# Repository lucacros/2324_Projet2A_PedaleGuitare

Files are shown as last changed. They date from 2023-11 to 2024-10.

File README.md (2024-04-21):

# Hi everyone 🖐️ & Welcome to our project: Multi-Effects Guitar Pedal 🎸🎛️

Hello music and technology fans! Welcome to the GitHub showcase for our multi-effects guitar pedal project. Here you'll find details, tools, and resources related to this exciting project. This is an academic project completed in 100 hours by the legendary trio: Luca CROSETTO, Jolan THOMASSET, and Camille LANFREDI

## 📖 Table of contents

- [📌 Présentation](#-présentation)
  - [📅 Management Section](#-management-section)
  - [🛠️ Hardware Section](#-hardware-section)
  - [💻 Software Section](#-software-section)
- [🚀 Contributions](#-contributions)
- [📜 Licence](#-licence)

## 📌 Présentation

Our multi-effects guitar pedal project aims to provide a versatile platform for guitarists, bringing together a variety of sound effects and audio processing tools in a single device. To achieve this, the guitar pedal will feature...

The project is divided into 3 parts: the first one is the project management, the second part is analog part, with the creation of the system's electronic board, and the third is the creation of the various digital audio effects. 
The second is the creation of the various digital audio effects.

## 📅 Management Section

In this section, you'll find everything to do with project management.

[Link to Management.md](Management.md)

## 🛠️ Hardware Section

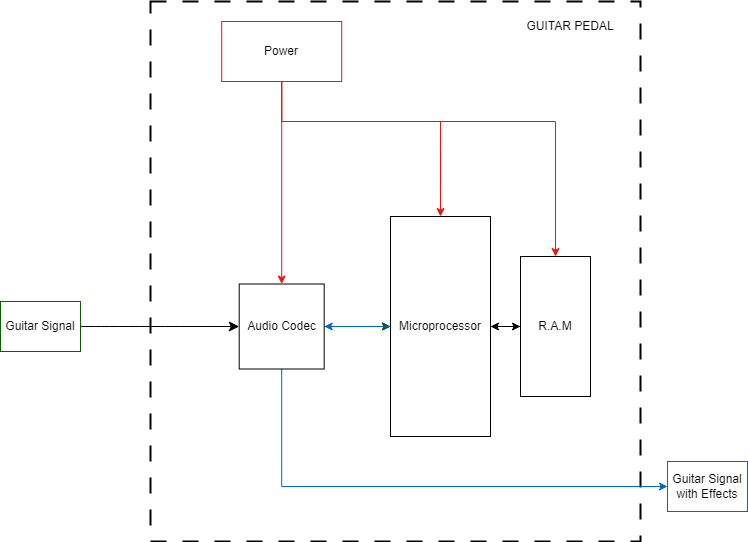
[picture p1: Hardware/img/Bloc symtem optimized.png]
 
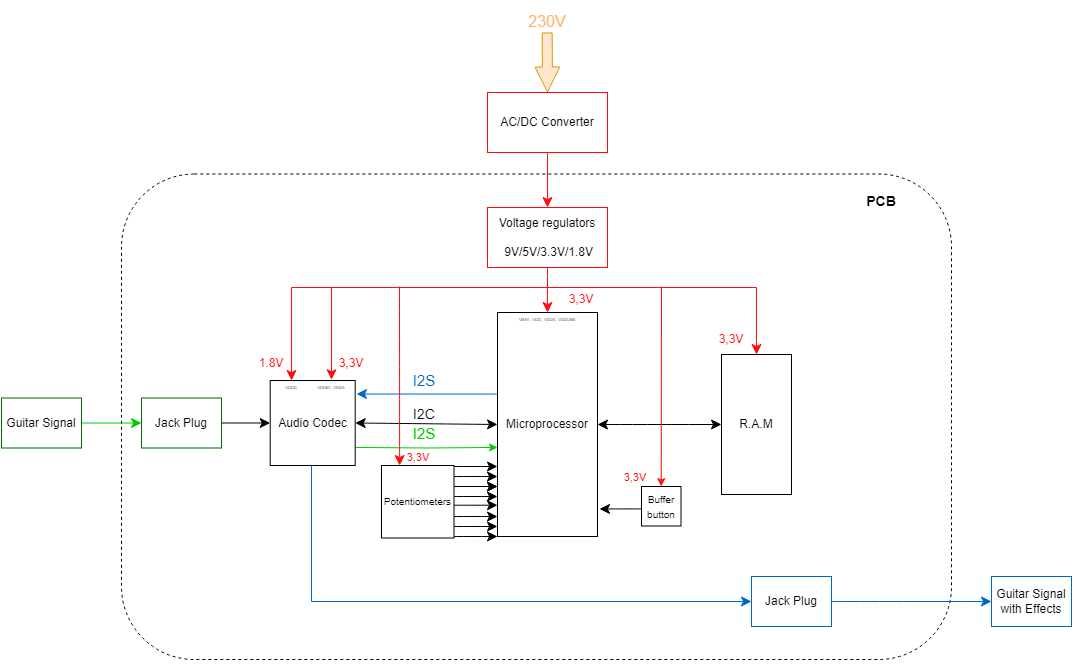
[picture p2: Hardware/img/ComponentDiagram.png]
 

### Power supply
To obtain these voltage levels, we use several voltage regulators. The first regulator is a switching regulator to go from 12V to 5V and then we use 2 linear regulators to obtain 3.3V and 1.8V. We first use a switching regulator to go from 12V to 5V, because switching regulators are more efficient than linear regulators when the voltage difference between input and output is high. We use linear regulators because they give a very clean output, with a minimum of noise.

We need to supply 2 different voltages: the first +3.3V to supply VDDA (for analogue part) and VDDIO (for Inputs/Outputs) and the second +1.8V to supply VDDD (for digital part).

| Components | Voltages |  Description |
|--- |:-: |:- |
| VDDIO | +3.3V | Power supply controls the digital I/O levels as well as the output level of LINE outputs. | 
| VDDD | +1.8V  | power supply controls the digital I/O levels as well as the output level of LINE outputs |
|  VDDA  | +3.3VA | Power supply is used for the internal analog circuitry including ADC, DAC, LINE inputs, MIC inputs, headphone outputs and reference voltages.|

#### Jack connecting
We use Jack switched for the input and the output of the guitar. The switched Jack allow us to have the choice between a mono-input or a stereo input and a mono-output and a stereo-output. 
When we connect a jack to this connector, the pins SN and TN are disconnected from the pins S and T. It can allow to have 2 connectors to have stereo but still use the 2 input of the codec to have a signal as powerful as a stereo input.
#### Buffer-Button
We use a buffer button to store a part of the sound of the guitar to apply several effects to it. It's one of the several options that offer the granular effect.
When the button is pressed, a signal is sent to the microprocessor. When it receives the signal, the microprocessor stores in the RAM the song it has received for a short time and continuously plays the part stored in the RAM.
#### Potentiometers
We use several potentiometers for all the settings of our effects, the gain, the shape, the reverb ect... All potentiometers are fitted with capacitors to eliminate unwanted noise and high frequencies.

They are 2 versions of the pcb :
| V | Recto | Verso  | Size |
|---|---|---|-----|
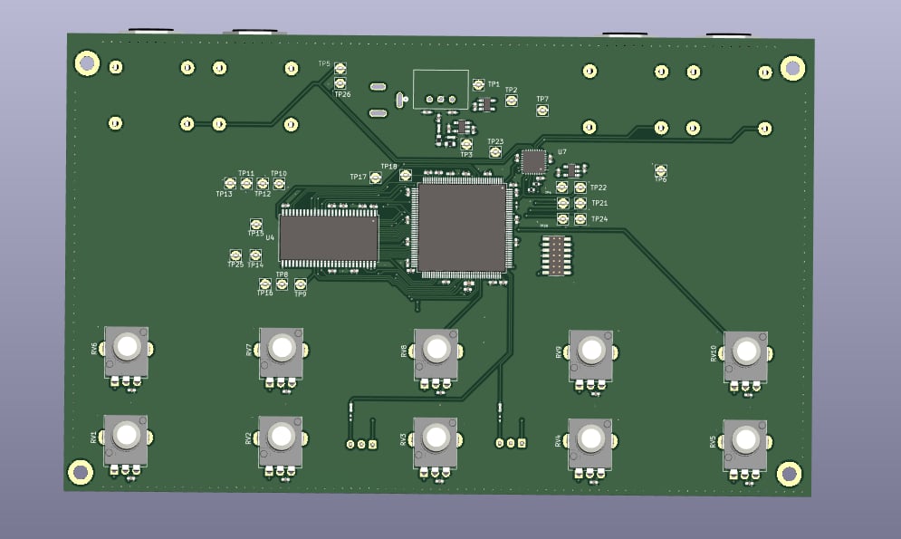
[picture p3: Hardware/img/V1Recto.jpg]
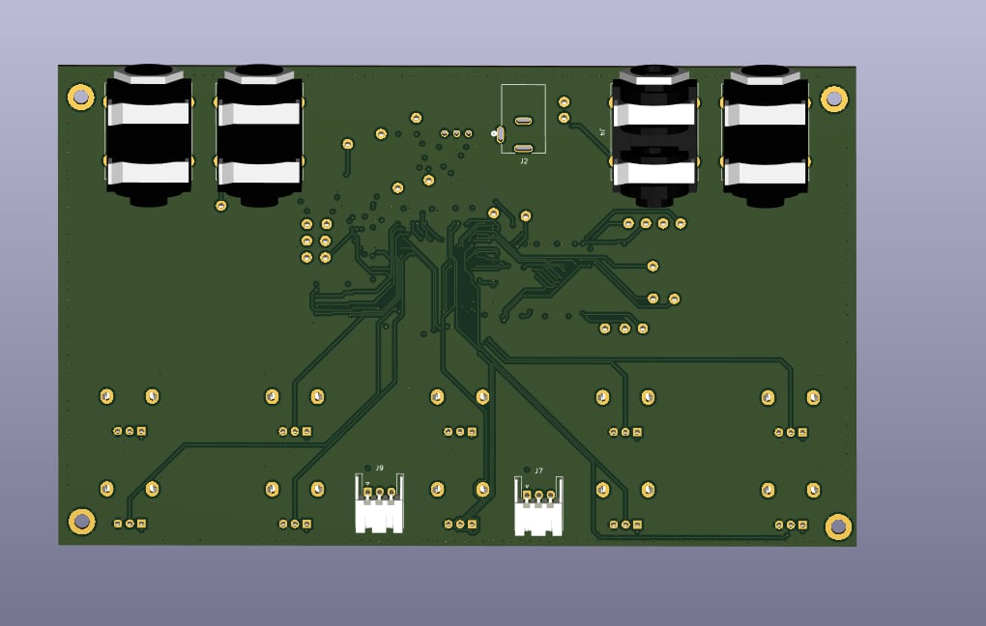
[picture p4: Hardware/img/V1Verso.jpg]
| V1.0|  | | 17 x 10.32 cm |
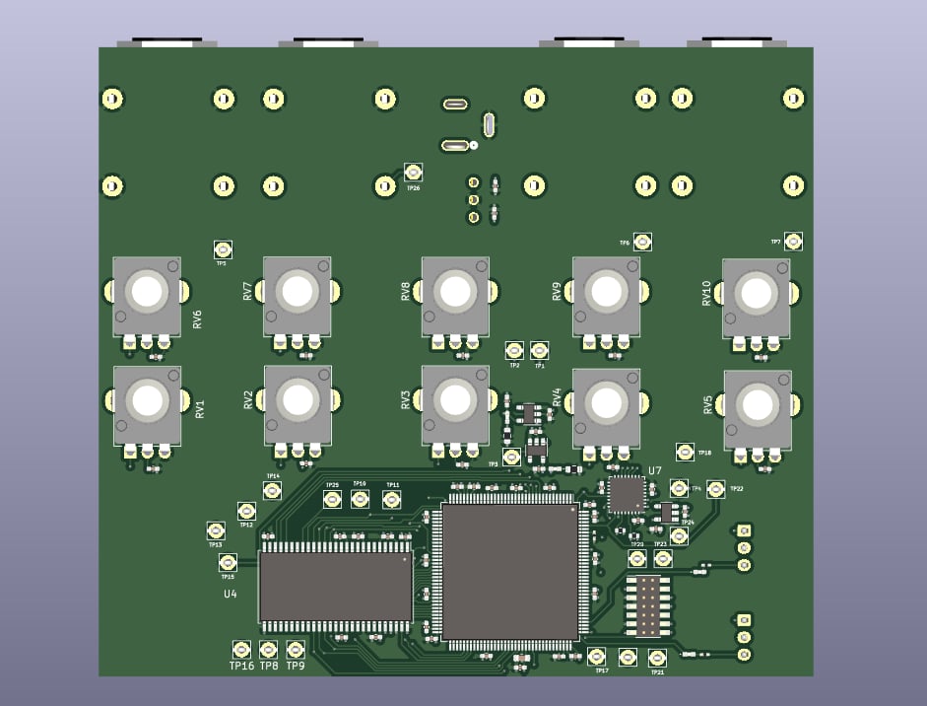
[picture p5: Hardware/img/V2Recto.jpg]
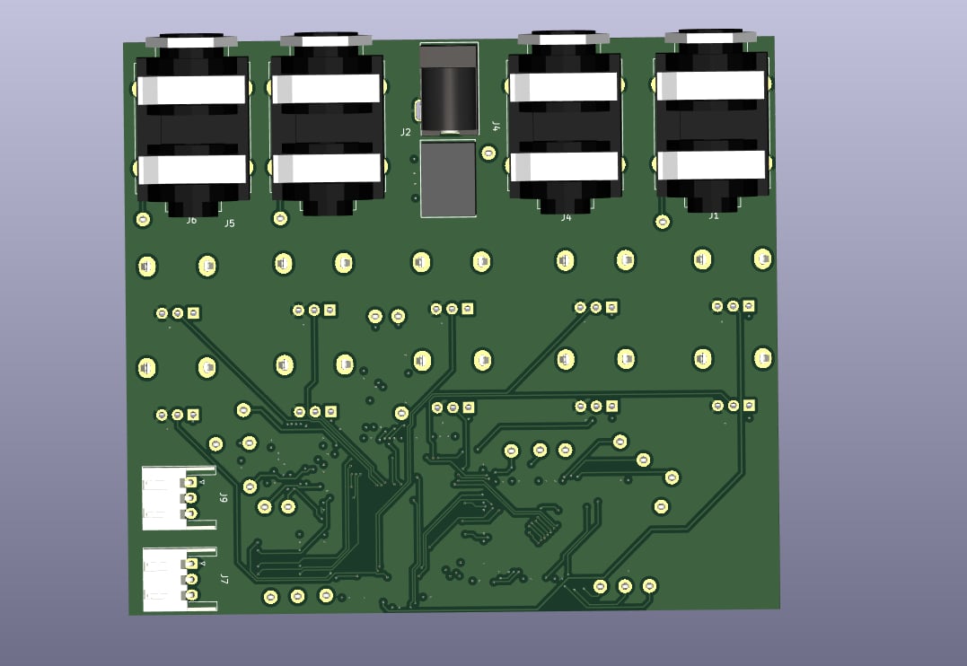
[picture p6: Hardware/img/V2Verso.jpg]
| V2.0|  | | 10.4 x 9.15 cm |
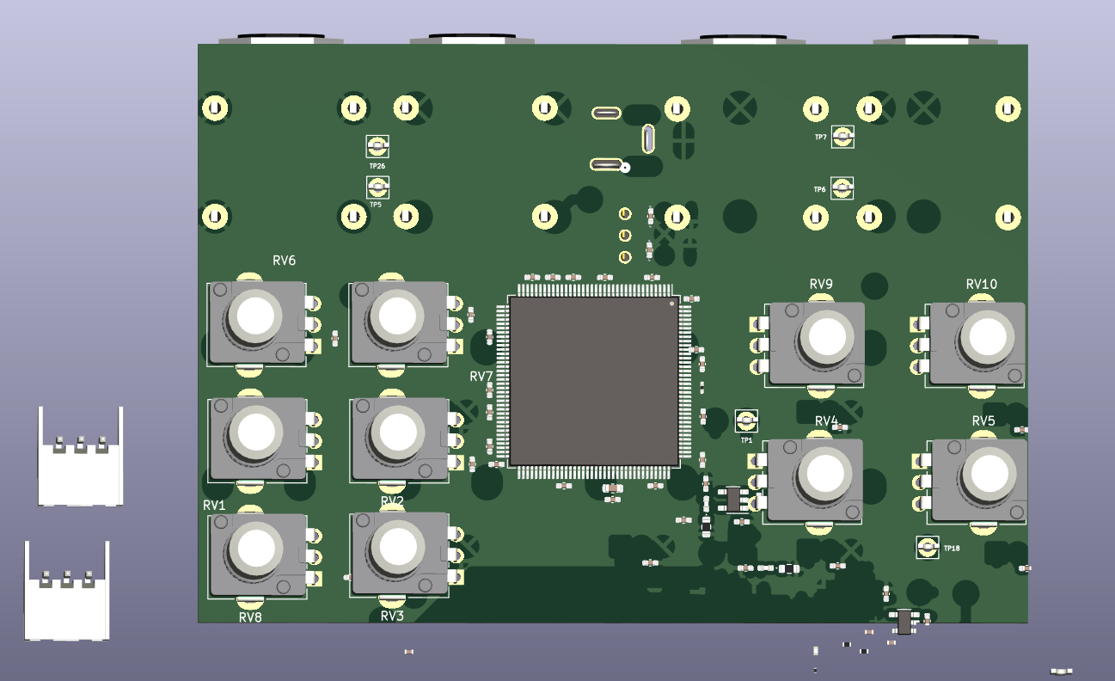
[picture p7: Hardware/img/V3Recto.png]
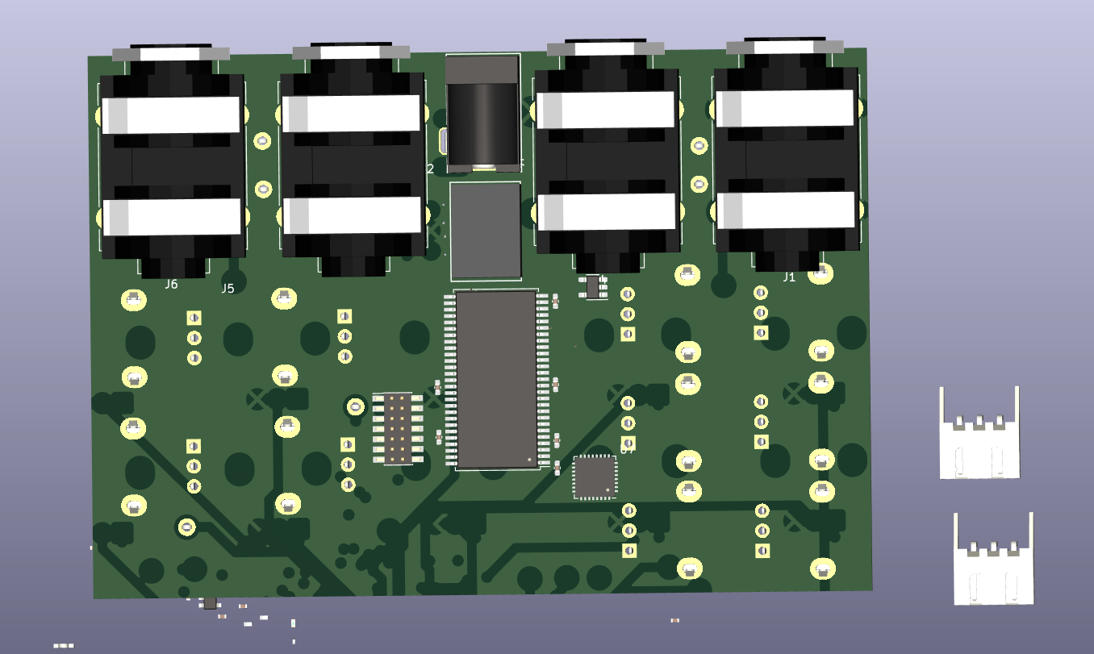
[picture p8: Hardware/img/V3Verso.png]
| V3.0| **WIP**  | **WIP**| 9.71 x 6.76 cm |

As you can see, the first version wasn't optimised. They is a lot of space between components and the design is not very good. That's why we did a new version witch to x2 smaller.

## 💻 Software Section

In this second part you will find everything that concerns the software part of the project. You'll find all the detailed audio effects programs and how they work.

[Link to Software Section](https://github.com/lucacros/2324_Projet2A_PedaleGuitare/tree/Software-Section)

## 🚀 Contributions

We would like to thank each person who helped us and provided support and information, such as:
- M. Nicolas PAPAZOGLOU
- M. Laurent FIACK
- M. Frédéric GERALDO

## 📜 Licence

The project is under the [SI TU VOLES T'ES MORT] license. Refer to the `LICENSE` file for more details.

---
Feel free to star this project (⭐) if you find it interesting!

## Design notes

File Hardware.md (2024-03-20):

# Here you are in the Hardware Section
You will find all specifications and things to understand it.
Enjoy your reading ! (Camille L)

## 📖 Table of contents
1. [List of components](#list-of-components)
2. [Hardware Specifications](#hardware-specifications)
3. [Installation](#installation)

## List of components
- [Link to List of Components](https://github.com/lucacros/2324_Projet2A_PedaleGuitare/blob/Hardware-Section/List%20of%20Components.md)

For more details on each component, refer to [Hardware Specifications](#hardware-specifications).

# Hardware Specifications
## Block Diagram

<p align="center">
  Block Diagram Optimized
</p>

Once the block diagram has been constructed, we can adapt it to the components used:

<p align="center">
  
</p>

## Power supply
The power dissipated in the electronic component used in switching mode is lower than when used in linear mode. They are 2 types of power for this pedal. Power of digital components and for analog components. That's why we have, the objective is to obtain the cleanest power source for our analog components such as : DAC and ADC. 
    
| Components | Voltages |  
|--- |:-: |
| MicroProc | +3.3V | 
|  Codec | VDDIO :+3.3V VDDD : +1.8V VDDA : +3.3V  | 
| RAM | +3.3V | 

To obtain these voltage levels, we use several voltage regulators. The first regulator is a switching regulator to go from 12V to 5V and then we use 2 linear regulators to obtain 3.3V and 1.8V. We first use a switching regulator to go from 12V to 5V, because switching regulators are more efficient than linear regulators when the voltage difference between input and output is high. We use linear regulators because they give a very clean output, with a minimum of noise.

### Switching power supply

The 17950x78 integrates both the input and output capacitors. Therefore, additional external input and output capacitors are normally not required.
The additional 100µF capacitor C1 is mounted as termination of the supply line and provides a slight damping of possible oscillations of the series resonance circuit represented by the inductance of the supply line and the input capacitance. This capacitor also prevents voltage overshoot during start up. the capacitor C3 allows fine tuning of load transcient voltage response.

### Linear power supplies
We use 3 linear regulators to lower the voltage to very clean outputs.

- 5V to 3.3V, for every components.


- 3.3V to 1.8V, for the audio codec.
<p align="center"><img src="img/Linear_supply_1V8.png></p>

## Audio Codec 

The SGTL5000 is a digital-to-analog (DAC) and analog-to-digital (ADC) audio codec. Its basic operation involvesconverting analog signals to digital for audio input and converting digital audio signals to analog for audio output. The essential pins include those for I2S communication, power supply, mode selection, audio input and output connections, as well as control pins to configure the codec based on application requirements.
Using the microcontroller, we will control the I2C codec and transmit the signals in I2S.

<p align="center">
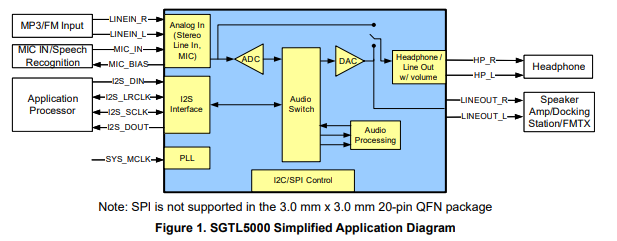
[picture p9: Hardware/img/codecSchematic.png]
  
</p>

### Power Section
To begin, we need to supply 2 different voltages: the first +3.3V to supply VDDA (for analogue part) and VDDIO (for Inputs/Outputs) and the second +1.8V to supply VDDD (for digital part).

| Components | Voltages |  Description |
|--- |:-: |:- |
| VDDIO | +3.3V | Power supply controls the digital I/O levels as well as the output level of LINE outputs. | 
| VDDD | +1.8V  | power supply controls the digital I/O levels as well as the output level of LINE outputs |
|  VDDA  | +3.3VA | Power supply is used for the internal analog circuitry including ADC, DAC, LINE inputs, MIC inputs, headphone outputs and reference voltages.|

### Configuration
The codec is clocked at the same frequency as the microprocessor. It communicates via I2C  and transmits its audio data in I2S.

| Label names | Codec Pins name | Description |
|---|---|---|
| **Guitar signal** | | 
| Ve_guitare_L | LINEIN_L | Left LINEIN | 
| Vs_guitare_L | LINEOUT_L | Left LINEOUT |
| Ve_guitare_R | LINEIN_R | Right LINEIN | 
| Vs_guitare_R | LINEOUT_R |Right LINEOUT |
| **Clock** | | 
| SYS_MCLK | SYS_MCLK | System master clock |
| **I2C** | | 
| SDA_I2S | CTRL_DATA | Mode: Serial Data |
| SCL_I2C | CTRL_CLK | Mode: Serial Clock |
| **I2S** | | 
| WS_I2S | I2S_LRCLK | Frame clock |
| CK_I2S | I2S_SCLK | Bit clock |
| DOUT_I2S | I2S_DOUT | Data output |
| SD_I2S | I2s_DIN | Data input |

## RAM 
For the granular effect, we need to store part of the sound that the guitar sends and read this sound. The RAM on the CPU was not enough to store all the information we needed, so we decided to use an external RAM.
To use the RAM we need to connect the Address pin to the CPU to send the information of which memory address we want to access in the RAM. The Data pin is used to send the information stored in the RAM to the CPU.
We have connected the RAM clock to the CPU clock so that the RAM and CPU work at the same speed.
## MicroProcessor 
The microprocessor is a crucial component in the guitar pedal system, responsible for controlling various functions, processing audio signals, and managing communication with other components. In this section, we'll delve into the specifications and details related to the microprocessor.
### MicroProcessor Pins
The microprocessor interacts with other components through various pins. Here are some essential pins and their functions:
### Power Supply Pins
| Pins | Voltages |  
|--- |:-: |
| VDDIO | +3.3V | 
| VDDD | +1.8V  | 
|  VDDA  | +3.3V | 
### Communication with RAM
The STM32F446ZC communicates with the RAM to handle memory operations. RAM is crucial for storing and accessing data during signal processing.
### Communication with Audio Codec
The microprocessor communicates with the audio codec (SGTL5000) using I2C for control and I2S for audio data transmission. The codec is responsible for converting analog signals to digital and vice versa.
- [Link to the Routing table](https://github.com/lucacros/2324_Projet2A_PedaleGuitare/blob/Hardware-Section/Routing_Table.md)
## Connectors
### Jack connecting
We use Jack switched for the input and the output of the guitar. The switched Jack allow us to have the choice between a mono-input or a stereo input and a mono-output and a stereo-output. 
When we connect a jack to this connector, the pins SN and TN are disconnected from the pins S and T. It can allow to have 2 connectors to have stereo but still use the 2 input of the codec to have a signal as powerful as a stereo input.
## Buffer-Button
We use a buffer button to store a part of the sound of the guitar to apply several effects to it. It's one of the several options that offer the granular effect.
When the button is pressed, a signal is sent to the microprocessor. When it receives the signal, the microprocessor stores in the RAM the song it has received for a short time and continuously plays the part stored in the RAM.
## Potentiometers
We use several potentiometer for all the settings of our effects, the gain, the shape, the reverb ect... All potentiometers are fitted with capacitors to eliminate unwanted noise and high frequencies.
## 💻 Installation
I recommend downloading the latest version of **KiCad** to reproduce the electronic board. For simulating amplifiers, consider using **Cadence Pspice** or **Microcap**. Use the **STCUBEIDE** software for programming the codec and microprocessor.
- **Pspice**: [Download Pspice](https://www.cadence.com/en_US/home/tools/pcb-design-and-analysis/analog-mixed-signal-simulation/pspice.html)
- **KiCad**: [Download KiCad](https://www.kicad.org/)
- **STCUBEIDE**: [Download STCUBEIDE](https://www.st.com/en/development-tools/stm32cubeide.html)

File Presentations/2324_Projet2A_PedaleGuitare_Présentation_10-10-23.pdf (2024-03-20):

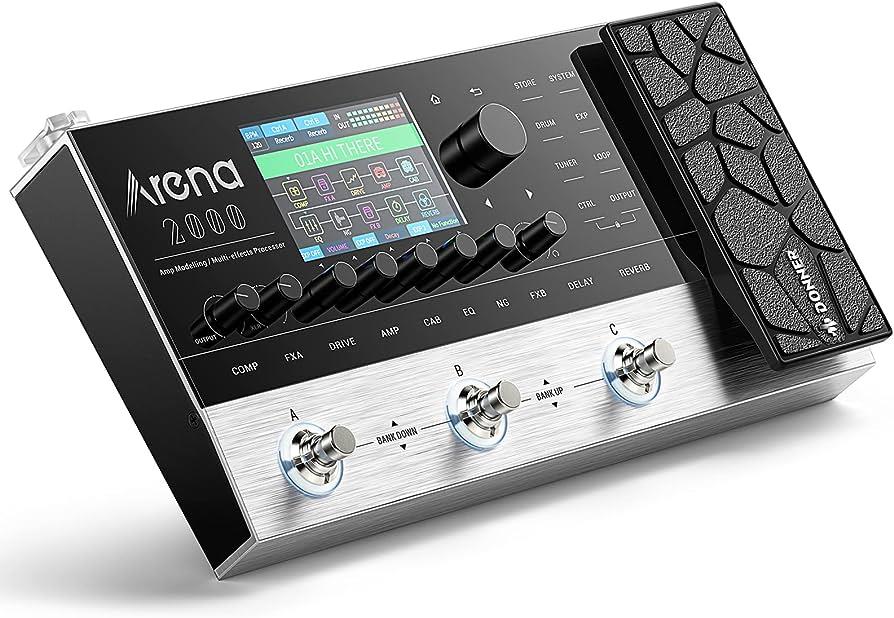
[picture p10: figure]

# Pédale Multi-Effets Numérique

Camille LANFREDI
Luca CROSETTO
Jolan THOMASSET

1

## Sommaire

- Introduction (3)
- Présentation du projet (4-5)
- État de l'art (6)
- Cahier des charges (7)
- Spécifications techniques (8-12)
20/03/2024 | Camille Luca Jolan | 2

## Introduction

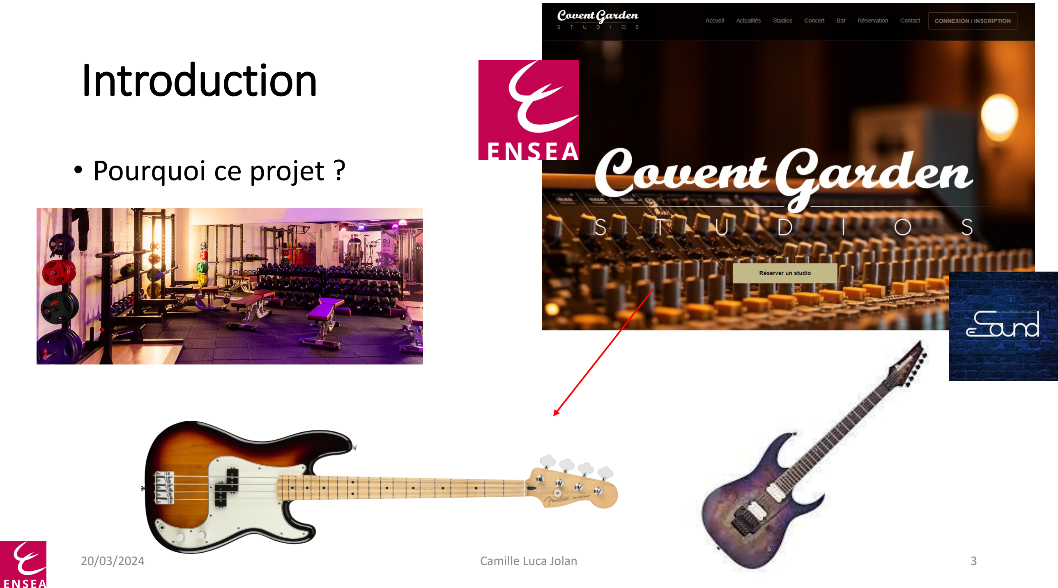
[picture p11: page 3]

- Pourquoi ce projet ?

## Présentation du projet 1/2

- Clients : Les adeptes de la musique (M. Fiack, M. Papazoglou) & les guitaristes
- Contexte – Contraintes
3 étudiants (2 élec-info / 1 signal-élec)
Une pédale à réaliser avec divers effets numériques ( Octaver, Saturation, Granulaire...) Sur une période de ~ 100h encadrées dans l'établissement + ∞ h à la maison
Choix des composants, création de notre propre PCB, choix des effets et implémentations.

## Présentation du projet 2/2

- Enjeux :
Tout à gagner (compétences), MAIS on s'ouvre à perdre la confiance d'un prof qui a cru en nous.
- Objectifs :
Partie Electronique : choix des composants / PCB / Assemblage
Partie informatique : Implémenter des transformations de signal sonore
- Coûts :
Budget alloué par l'établissement, ~60-100€ par personne

## Etat de l'art

- Première pédale d'effet inventé en 1962 (La Maestro Fuzz Tone).
- A partir des années 80, apparitions des pédales numériques.
- Année 90, création des pédales multi-effets.
- Année 2000, création des plugins.

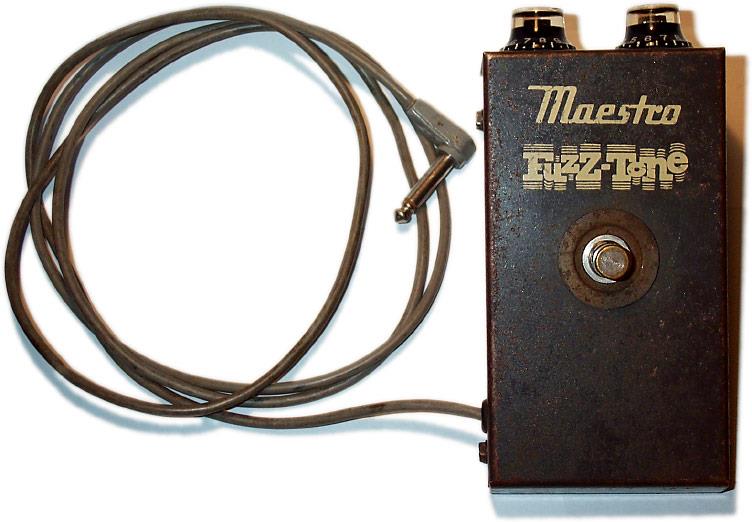
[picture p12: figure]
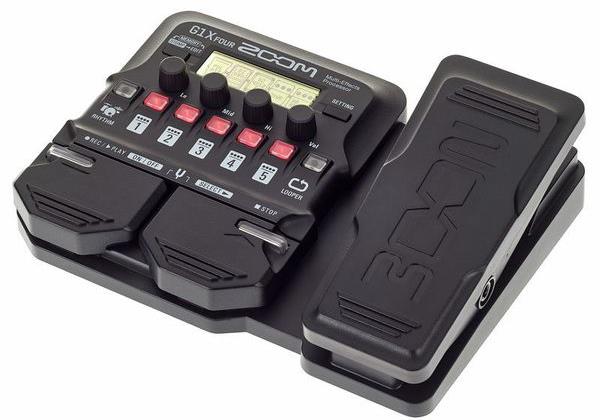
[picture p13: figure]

## Cahier des charges

- Fil Conducteur
Fabrication d'une pédale multi-effet.
- Spécifications techniques :
Représentation du système
Utilisation d'un codec audio.
Utilisation d'un microprocesseur lié à une RAM externe. Interprétation physique d'effet audio
Implémentation d'un effet audio numériquement Réussir à implémenter un effet "Granulaire"

Spécifications techniques - Représentation du système

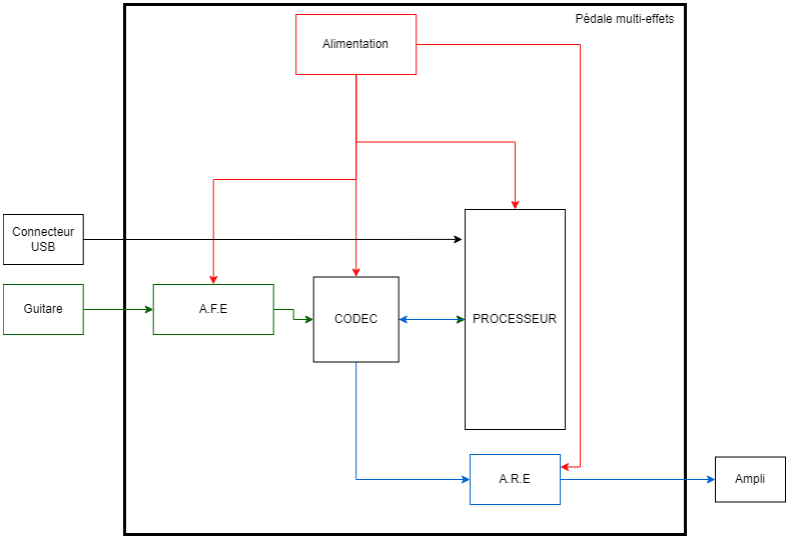
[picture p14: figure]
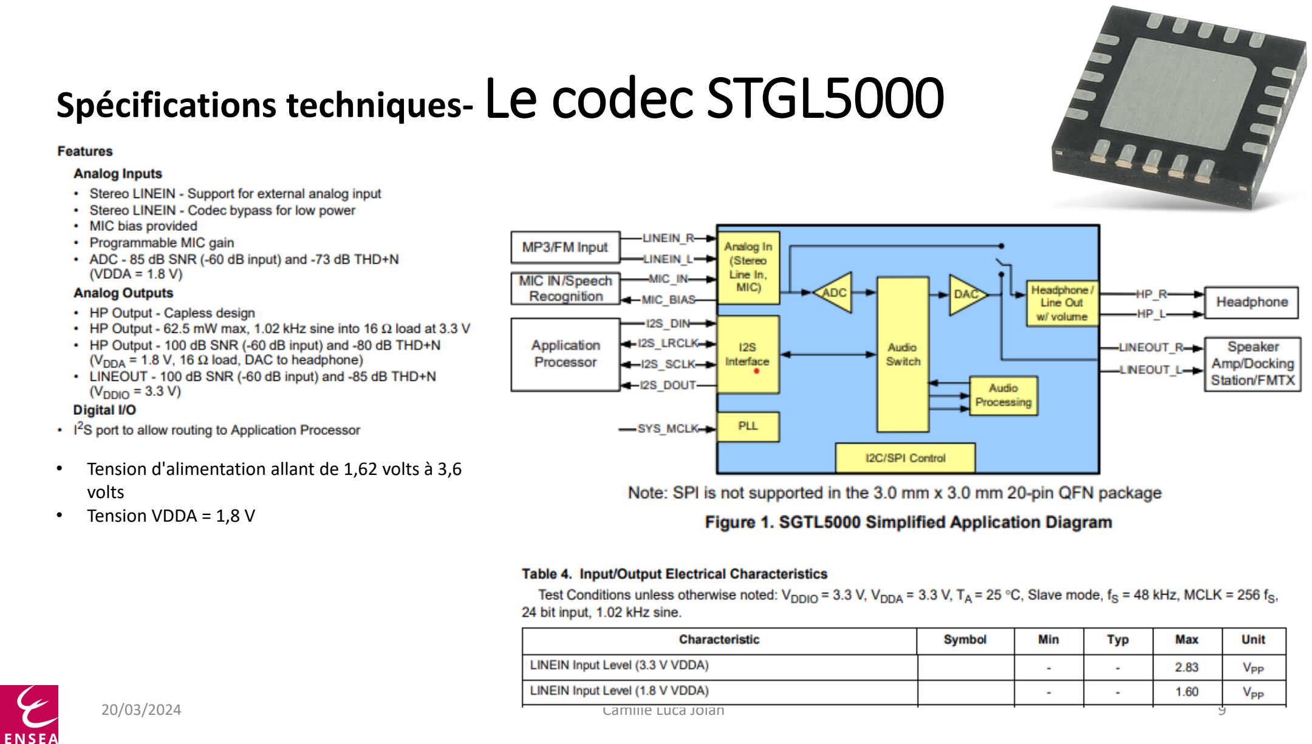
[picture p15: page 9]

Spécifications techniques- Le codec STGL5000

- Tension d'alimentation allant de 1,62 volts à 3,6 volts
- Tension VDDA = 1,8 V

Tension d'entrée max LINEIN_R et _L
Vmax = VDDA * 10^(Niveau d'entrée maximal en dB / 20)
Vmax = 1,8 V * 10^(-60 dB / 20) = 0,056 V

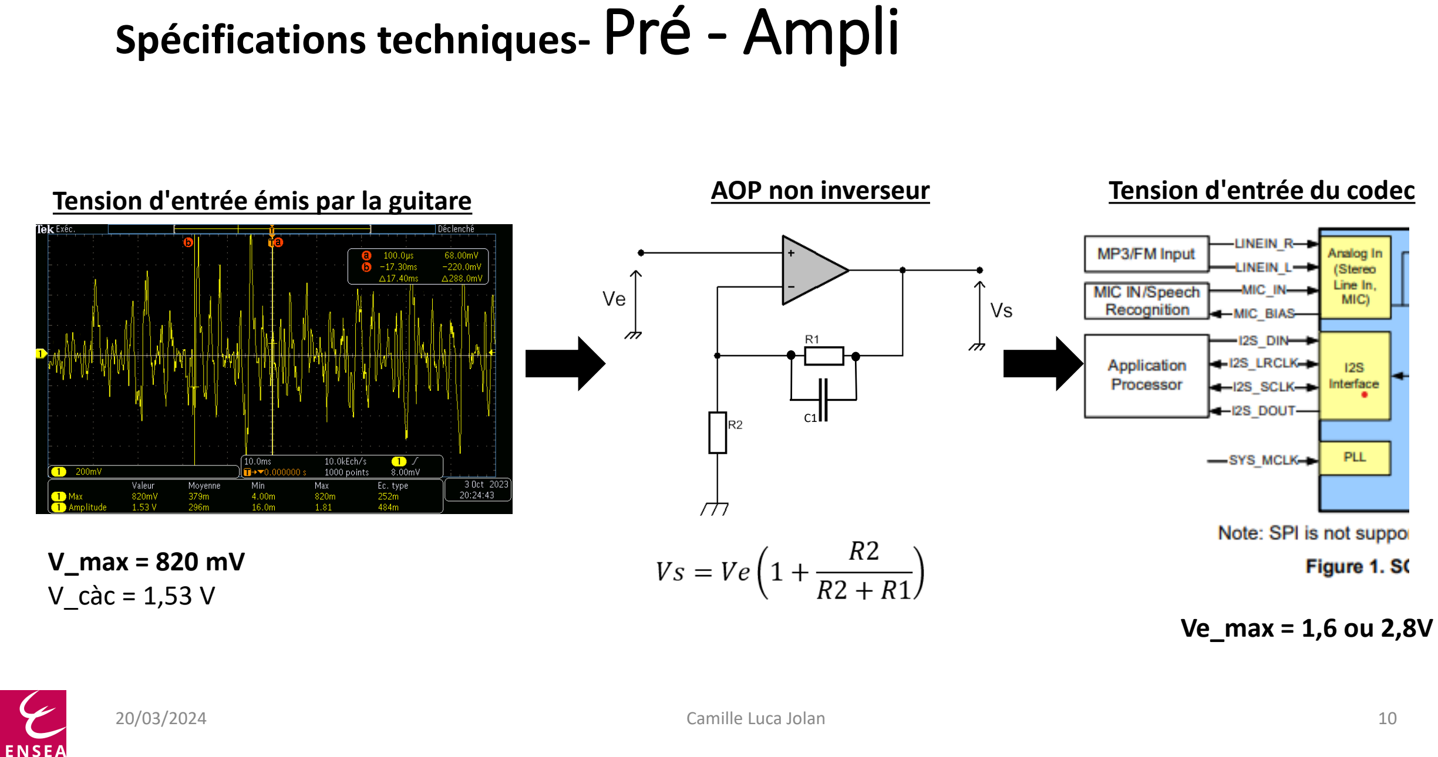
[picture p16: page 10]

Spécifications techniques- Pré - Ampli

Tension d'entrée émis par la guitare

V_max = 820 mV
V_càc = 1,53 V
AOP non inverseur | Tension d'entrée du codec

Ve_max = 1,6 ou 2,8V

C1

Spécifications techniques - LE Microprocesseur

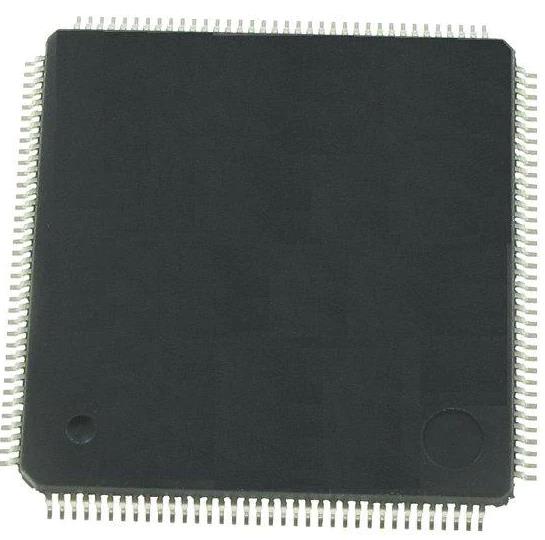
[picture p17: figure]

STM32f446ZCT6

Alimentation : Vdd et Vss = 3,3V

Mémoire :
- 512 Ko à 180 MHz
- 128 Ko RAM

Horloge : 4 à 26 MHz

114 entrées/sorties :

Interfaces de communication : SPI, I2C, UART, I2S

Inter-integrated sound (I2S) :
- Disponibles sur SP1, SP2 et SP3
- Fréquence d'échantillonnage : 8 kHz à 192 kHz
- Résolution de 16/32 bits

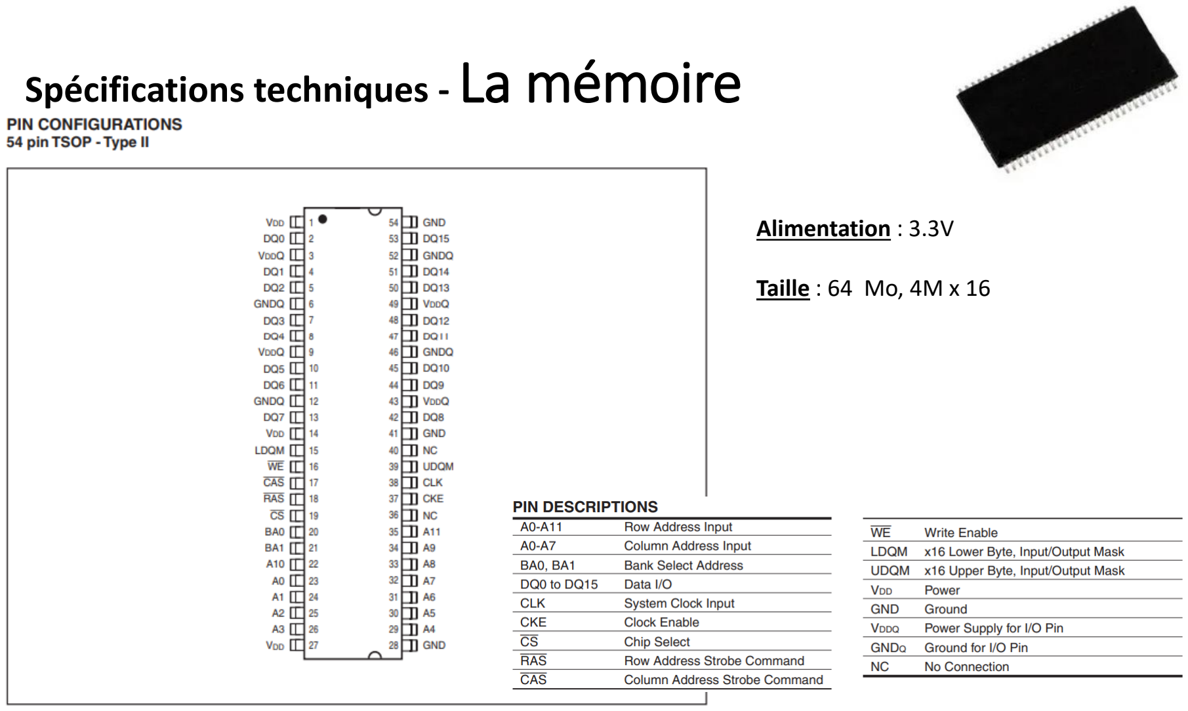
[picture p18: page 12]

Spécifications techniques - La mémoire

Alimentation : 3.3V

Taille : 64 Mo, 4M x 16

Spécifications techniques

## Implémentation

- Quel langage ? C, C++, Python
- Codage en amont : Librairie Portaudio (C++) permet d'obtenir une Input/Output son temps réel.
- Documentation sur la Physique de la modulation de notre signal sonore et l'effet qui correspond à cette modulation
- Code sur VCS & Suivi Github

Spécifications techniques

## L'Effet Granulaire

- Etude de l'effet à l'aide de Logiciel (durée d'un grain = typiquement de 1 à 100 ms).

La synthèse granulaire est une technique de traitement du son qui divise un signal sonore en petits grains (fragments) Ensuite les grains peuvent être manipulés de différentes manières pour créer un effet souhaité.

- Pitch : Contrôle la hauteur ou la fréquence du son granulaire généré
- Density : Contrôle la fréquence à laquelle de nouveaux grains sont générés.
- Shape : Permet d'influencer la façon dont les grains sont lus (passage enveloppe linéaire à exponentielle)
- Feedback : Le potard feedback détermine la quantité de signal granulaire qui est renvoyée. Plus on augmente le feedback, plus une partie du signal granulaire peut être renvoyée dans le processus, créant une boucle de rétroaction.
- Reverb : en augmentant la reverb, on crée une ambiance spatiale plus grande autour du son granulaire, donnant l'impression que le son se propage dans un espace plus grand

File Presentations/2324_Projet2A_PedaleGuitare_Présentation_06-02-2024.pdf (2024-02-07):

# Pédale Multi-effets (PME)

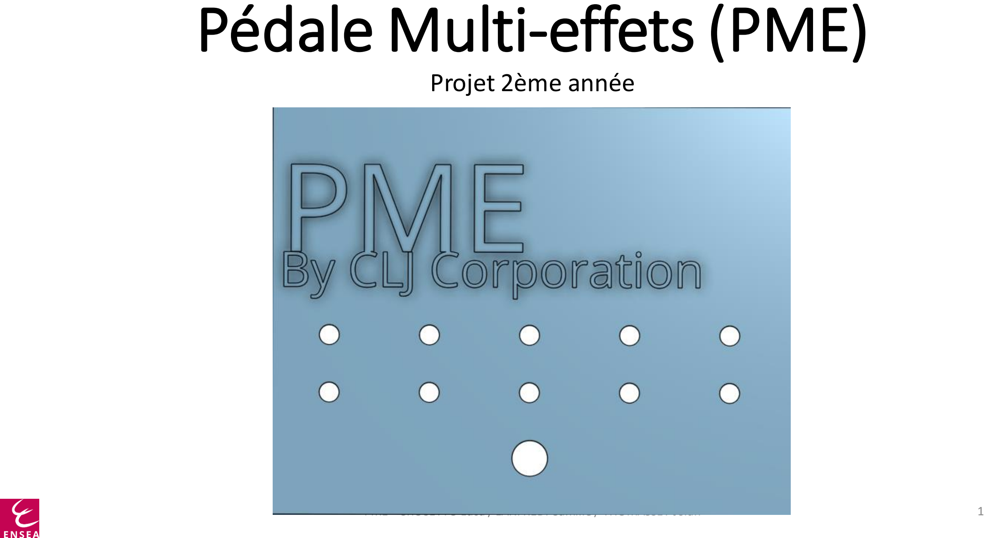
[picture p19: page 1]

Projet 2ème année

PME - CROSETTO Luca / LANFREDI Camille / THOMASSET Jolan | 1

## Objectifs atteints (12 Séances)

- Schéma PCB
- Composants
- Tests sur Guitare
- Prise en main du langage informatique FAUST
- Utilisation du CODEC avec restitution du signal entrée / sortie sur une carte son (STM32, CubeIDE).
- Création d'un effet simple de distorsion.

Cahier des charges
Créer une Pédale de Guitare :
- Carte électronique
- Boitier
Coder des Effets Numérique :
- IN/OUT Codec
- Effet simple
- Effet complexe

## Objectifs restants (10 séances)

- Création d'un boitier pour la pédale
- Finalisation du PCB.
- Prendre en compte les potentiomètres lors de la réalisation des effets.
- Effet numérique complexe
- Management (impact environnemental, etc...)

Cahier des charges
Créer une Pédale de Guitare :
- Carte électronique
- Boitier
Coder des Effets Numérique :
- IN/OUT Codec
- Effet simple
- Effet complexe

## Bilan SOFTWARE

- Réalisation d'un effet de Reverb en langage Faust

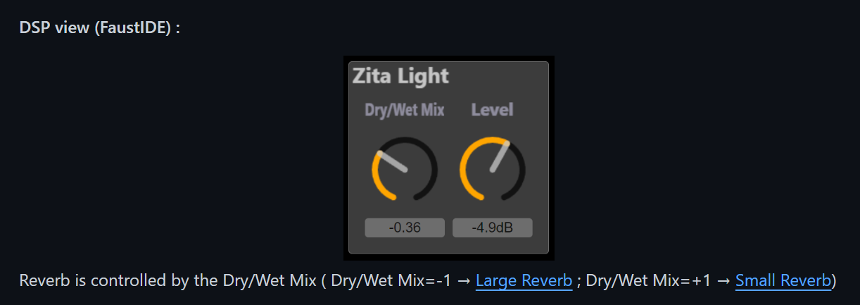
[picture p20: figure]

## Bilan SOFTWARE

- Restitution entrée/sortie par le biais d'un CODEC audio avec STM32

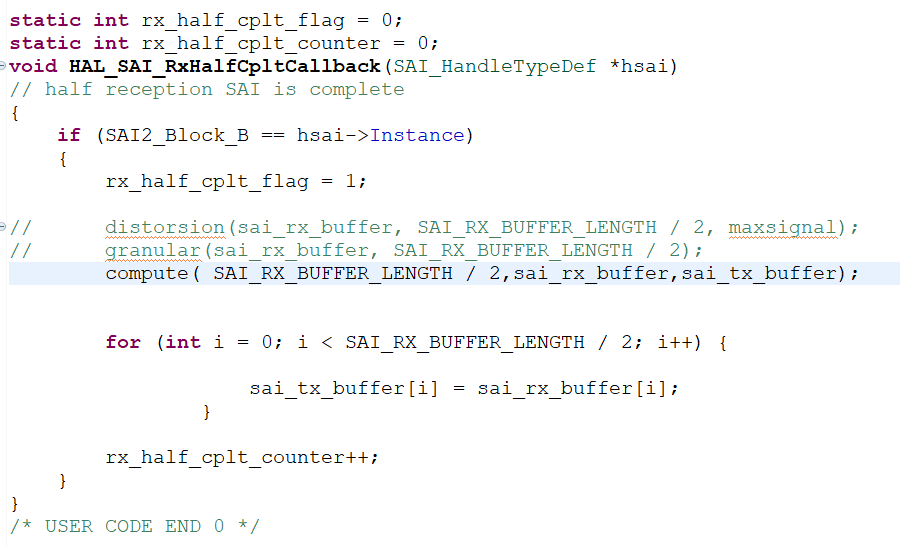
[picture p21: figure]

Int16_t ou Float
?

Question

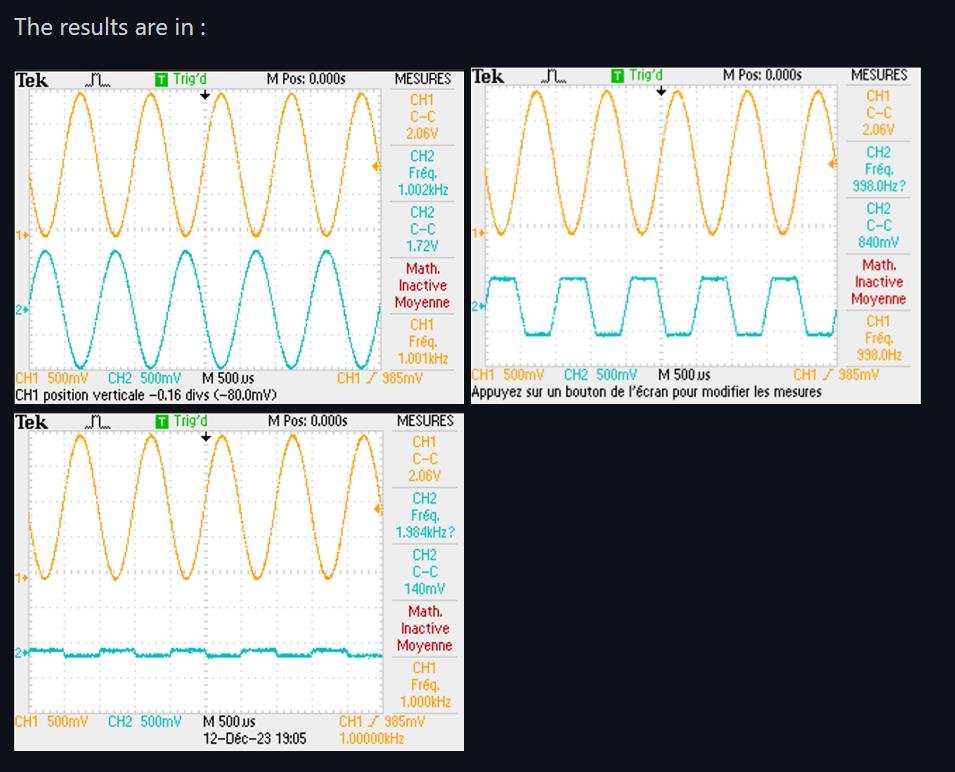
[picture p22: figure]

## Bilan SOFTWARE

- Effet Simple Distorsion
(distorsion.c, distorsion.h)

Ajustement de la valeur
Max à attribuer.

## Bilan SOFTWARE

- Effet Reverb by Faust (convert in Cpp)

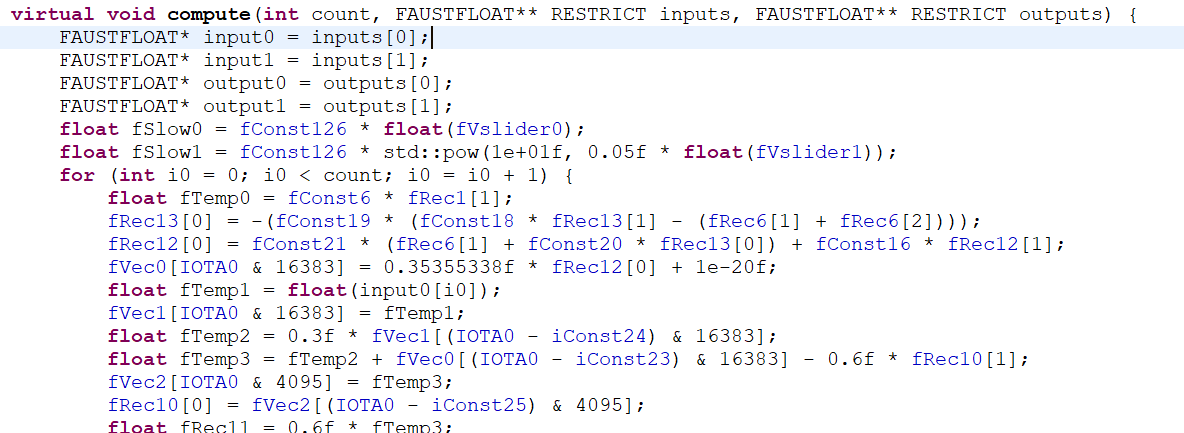
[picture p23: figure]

- Identification partie du code Intéressante
- Utilisation du code dans STM32

## Modélisation 3D du boitier de la pédale

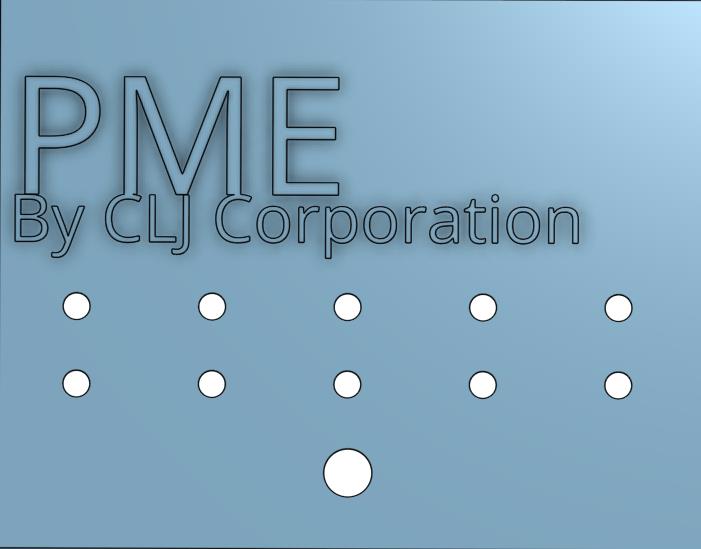
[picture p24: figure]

Vue de dessus

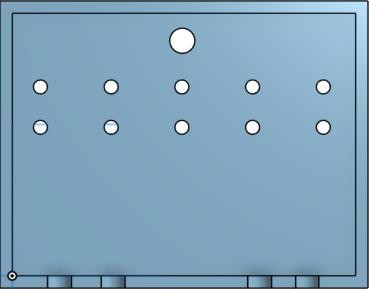
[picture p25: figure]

Vue de dessous

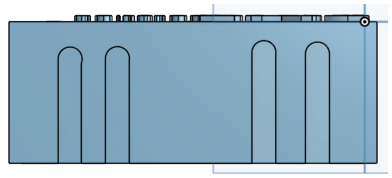
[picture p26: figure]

Vue de derrière

## Bilan HARDWARE

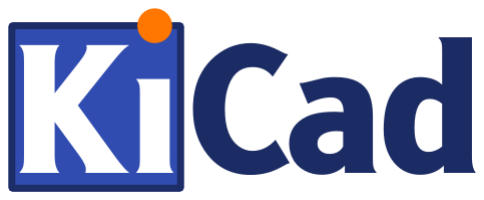
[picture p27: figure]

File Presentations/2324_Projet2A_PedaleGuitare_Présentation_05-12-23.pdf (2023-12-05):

# La Pédale de Guitare Numérique

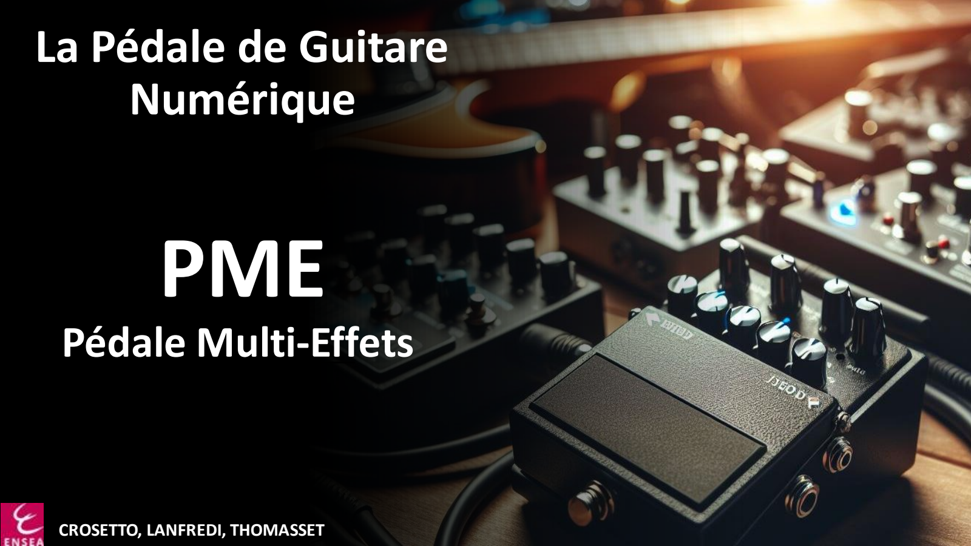
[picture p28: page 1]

# PME

## Pédale Multi-Effets

CROSETTO, LANFREDI, THOMASSET

# Sommaire

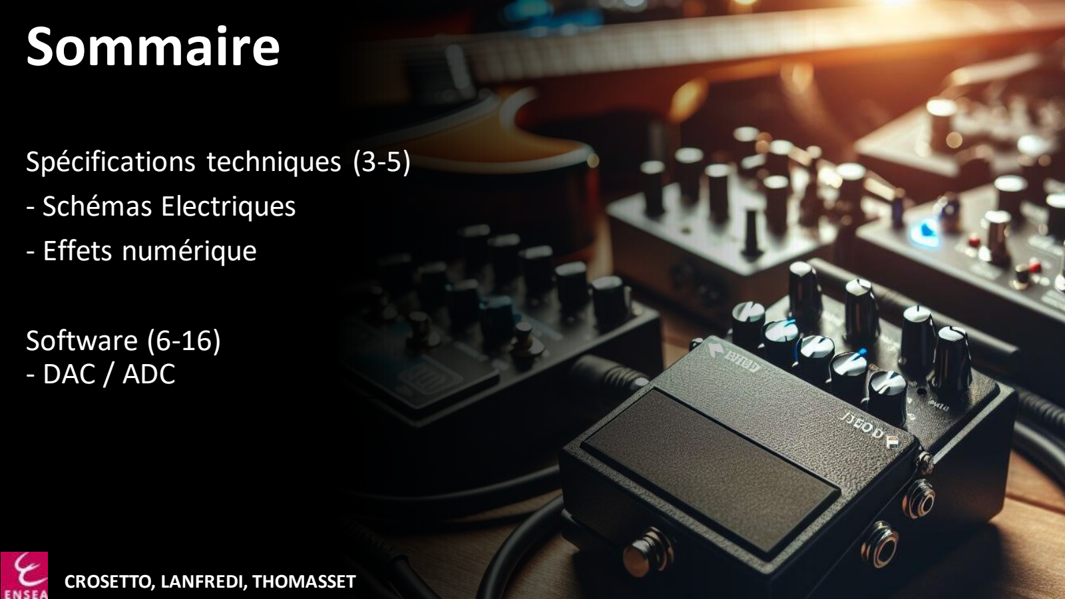
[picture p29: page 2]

Spécifications techniques (3-5)
- Schémas Electriques
- Effets numérique

Software (6-16)
- DAC / ADC

CROSETTO, LANFREDI, THOMASSET

## Spécifications techniques - Schéma Bloc de la pédale

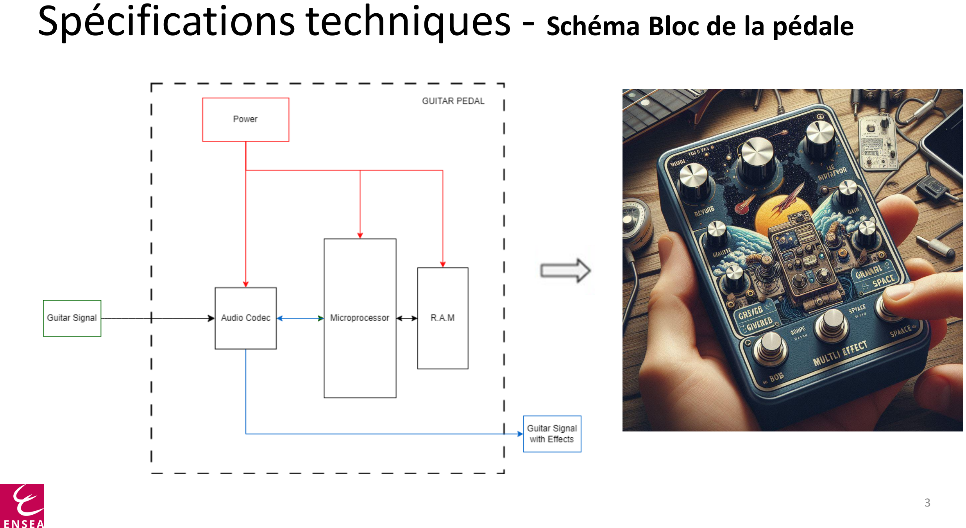
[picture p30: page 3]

## Spécifications techniques - Schéma Bloc de la pédale

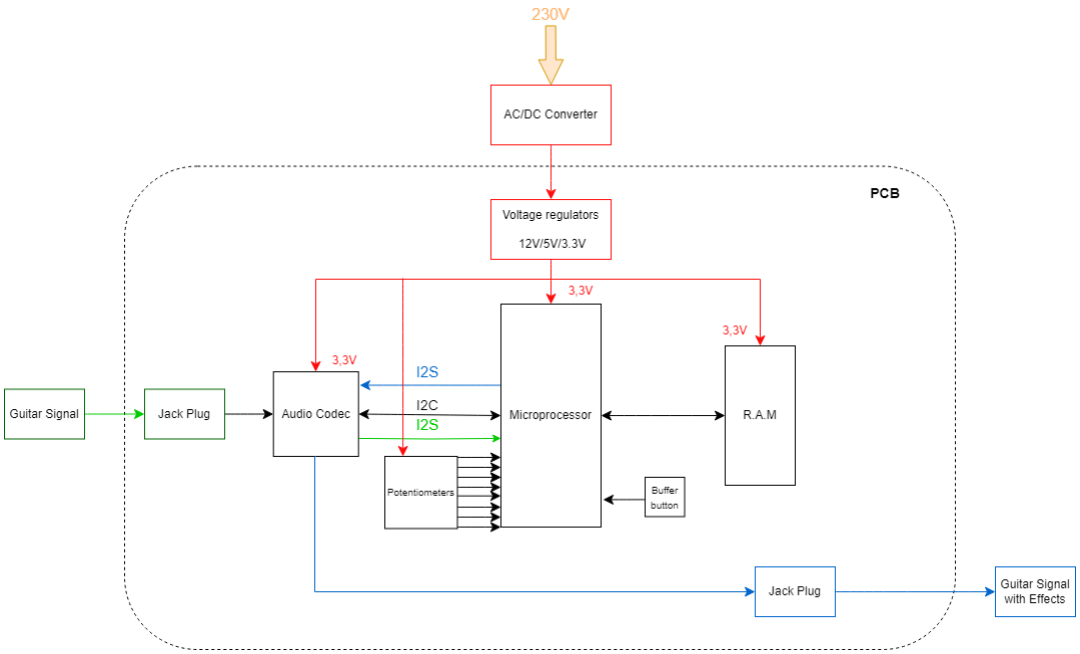
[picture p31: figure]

## Spécifications techniques - Schéma électrique

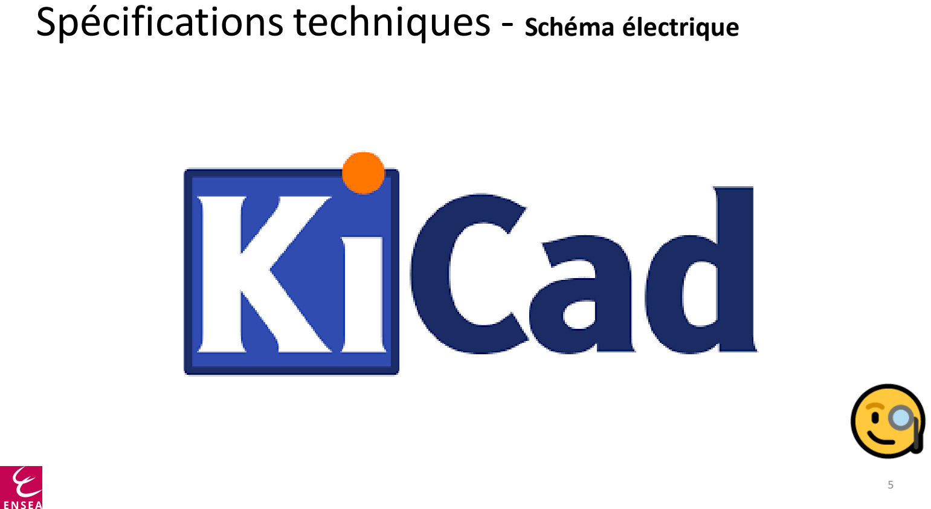
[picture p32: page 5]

## Software


- Coder un Effet en FAUST et le générer en C


- Capturer et afficher IN/OUT Audio sur

Reverb effect control

Software | Capturer et afficher IN/OUT Audio sur


# CODEC

Objectif Finale

EFFECT

With effect


With effect

Software | Capturer et afficher IN/OUT Audio sur

ADC; DAC; EFFECT

Analog Signal
With Effect

Objectif pour tester l'effet avant de se lancer dans l'utilisation du CODEC


Software | Capturer et afficher IN/OUT Audio sur
ADC | DAC

Dans un premier temps :

Software | Capturer et afficher IN/OUT Audio sur

Démarrage avec le DAC ( partie avec l'ADC déductible )

Ioc view

DAC codé sur 12 bits

Valeur comprise entre 0 et 4095

Étape 1 : afficher un signal qui monte jusqu'à 4095 et qui redescend à 0

DAC

Software | Capturer et afficher IN/OUT Audio sur

Étape 2 : Utilisation d'un DMA (Direct memory access)


Software | Capturer et afficher IN/OUT Audio sur

Étape 2 : Utilisation d'un DMA

Déclenchement par TIMER (et non plus pas Trigger)


Création du DMA
Stocker une période et la jouer en boucle (12bits)

Configuration du TIMER

TIM8 sur APB2

Clock configuration view

Fréquence Audio 48kHz

Le taux d’échantillonnage pour l’audio “professionnel”

(180.10⁶)/(48.10³) = 3750

ARR * PSC = 3750

ARR = 3750 –1 PSC = 1

DAC

Software | Capturer et afficher IN/OUT Audio sur

Configuration du TIMER


Relie TIM8 automatiquement
Création du Buffer

Dent de scie pour 48kHz, MAX 4096 MIN 0

On mesure bien une fréquence de 1kHz à l'oscilloscope

DAC

Software | Capturer et afficher IN/OUT Audio sur
ADC
ADC fonctionne entre 0 et 3,3 V | [-0,7 ; +3,3] | GBF sinus 1V/div.

Mise en Place d'interruptions; ADC; DAC; Buffer

Software | Capturer et afficher IN/OUT Audio sur
ADC

Software | Capturer et afficher IN/OUT Audio sur
ADC DAC


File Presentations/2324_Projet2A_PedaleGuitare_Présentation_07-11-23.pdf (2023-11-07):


# Pédale Multi-Effets Numérique

## Camille LANFREDI Luca CROSETTO Jolan THOMASSET

07/11/2023 | 1

# Sommaire

## - Spécifications techniques (8-12) - Schémas Electriques - Effets numérique

# Spécifications techniques - Schéma Bloc de la pédale


# Spécifications techniques – Préamplificateur


07/11/2023 | Camille Luca Jolan | 4

Tension d'entrée émis par la guitare

V_max = 820 mV
V_càc = 1,53 V
AOP non inverseur | Tension d'entrée du codec

Ve_max = 1,6 ou 2,8V

C1

# Spécifications techniques – Préamplificateur

## - Simulation


# Spécifications techniques – Préamplificateur et

# Amplificateur de sortie


# Spécifications techniques – Connexion Codec / µP


- Connexion I2C pourla communication
- Communication série (SPI ou I2S) pour l'audio
- Entrées/sorties audio
- Alimentation/Miseà la terre et autres connexions

Broches du codec SGTL5000 (selon la datasheet typique) : •SDA: Broche de données pour l'I2C
•SCL: Broche d'horloge pour l'I2C
•RESET: Broche de réinitialisation du codec
•MCLK: Horloge maître (peut être utilisée pour I2S) •LRCLK: Horloge de canal gauche/droite (utilisée pour I2S) •BCLK: Horloge de bits (utilisée pour I2S)
•DIN: Données d'entrée (utilisée pour I2S)
•DOUT: Données de sortie (utilisée pour I2S)
•MIC/GPIO: broche de micro ou de GPIO (entrée/sortie générale) •VDDIO: Alimentation pour les signaux d'entrée/sortie
•VDDA: Alimentation analogique
•VDDD: Alimentation numérique

# Spécifications techniques - Connexion µP/RAM


- Connexion I2C pourla communication
- Communication série (SPI ou I2S) pour l'audio
- Entrées/sorties audio
- Alimentation/Miseà la terre et autres connexions

Brochage de la mémoire :
•D0-D15 : Lignes de données bidirectionnelles. •A0-A11 : Lignes d'adresse pour la mémoire •BA0-BA1 : Lignes de rangée de mémoire. •WE : Broche d'écriture.
•CAS : Broche de sélection de colonne. •RAS : Broche de sélection de rangée. •CLK : Signal d'horloge.
•CS : Broche de sélection de puce.

# Spécifications techniques – Acheminement du signal


# Effets Numérique


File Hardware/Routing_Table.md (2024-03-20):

# Routing table of microprocessor, ram and codec
[Return to Hardware Section](https://github.com/lucacros/2324_Projet2A_PedaleGuitare/tree/Hardware-Section)

| Label | Microprocesseur (STM32F446ZC) | RAM (42-45S16400J )  | Codec (SGTL5000) | Description |
|---|---|---|---|---|
| BOOT0 | BOOT0| | | Boot Mode Selection (Microprocessor) |
| NRST | NRST | | | Reset (Microprocessor) |
| P0 | PA0  | | | General Purpose I/O (Microprocessor) |
| P1 | PA1  | | | General Purpose I/O (Microprocessor) |
| SYS_MLK | PA1  | | SYS_MLK | System Master Clock (Microprocessor) |
| SWDIO | PA13 | | | SWD Debug I/O (Microprocessor) |
| SWCLK | PA14 | | | SWD Debug Clock (Microprocessor) |
| P2 | PA2  | | | General Purpose I/O (Microprocessor) |
| P3 | PA3  | | | General Purpose I/O (Microprocessor) |
| P4 | PA4  | | | General Purpose I/O (Microprocessor) |
| P5 | PA5  | | | General Purpose I/O (Microprocessor) |
| P6 | PA6  | | | General Purpose I/O (Microprocessor) |
| P7 | PA7  | | | General Purpose I/O (Microprocessor) |
| P8 | PA8  | | | General Purpose I/O (Microprocessor) |
| P8 | PB0  | | | General Purpose I/O (Microprocessor) |
| P9 | PB1  | | | General Purpose I/O (Microprocessor) |
| SCL_I2C | PB10 | | CTRL_CLK | I2C Clock (Microprocessor) |
| SDA_I2C | PB11 | | CTRL_DATA  | I2C Data (Microprocessor) |
| WS_I2S | PB12 | | I2S_LRCLK  | I2S Word Select (Microprocessor) |
| CK_I2S | PB13 | | I2S_SCLK | I2S Clock (Microprocessor) |
| SD_I2S | PB15 | | I2S_DIN | I2S Data (Microprocessor) |
| BOOT1 | PB2  | | | Boot Mode Selection (Microprocessor) |
| SWO | PB3  | | | Serial Wire Output (Microprocessor) |
| SDCKE1 | PB5  | CKE | | Clock Enable for SDRAM (Microprocessor) |
| SDNE1 | PB6  | CS | | Chip Select for SDRAM (Microprocessor) |
| DOUT_I2C | PB9  | | I2S_DOUT | I2C Data Output (Microprocessor) |
| SDNWE | PC0  | WE | | Write Enable for SDRAM (Microprocessor) |
| OSC32_IN | PC14 | | | External 32 kHz Oscillator Input (Microprocessor) |
| OSC32_OUT | PC15 | | | External 32 kHz Oscillator Output (Microprocessor) |
| D2 | PD0  | DQ2 | | Data Bit 2 (RAM) |
| D3 | PD1  | DQ3 | | Data Bit 3 (RAM) |
| D15 | PD10 | DQ15  | | Data Bit 15 (RAM) |
| D0 | PD14 | DQ0 | | Data Bit 0 (RAM) |
| D1 | PD15 | DQ1 | | Data Bit 1 (RAM) |
| PD2 | | | | (Unused) |
| D13 | PD8  | DQ13  | | Data Bit 13 (RAM) |
| D14 | PD9  | DQ14  | | Data Bit 14 (RAM) |
| NBL0 | PE0  | LDQM  | | Latch Enable Data Input/Output (RAM) |
| NBL1 | PE1  | UDQM  | | Output Enable for Data Output (RAM) |
| D7 | PE10 | DQ7 | | Data Bit 7 (RAM) |
| D8 | PE11 | DQ8 | | Data Bit 8 (RAM) |
| D9 | PE12 | DQ9 | | Data Bit 9 (RAM) |
| D10 | PE13 | DQ10  | | Data Bit 10 (RAM) |
| D11 | PE14 | DQ11  | | Data Bit 11 (RAM) |
| D12 | PE15 | DQ12  | | Data Bit 12 (RAM) |
| D4 | PE7  | DQ4 | | Data Bit 4 (RAM) |
| D5 | PE8  | DQ5 | | Data Bit 5 (RAM) |
| D6 | PE9  | DQ6 | | Data Bit 6 (RAM) |
| A0 | PF0  | A0 | | Address Bit 0 (RAM) |
| A1 | PF1  | A1 | | Address Bit 1 (RAM) |
| SDNRAS | PF11 | RAS | | Row Address Strobe (RAM) |
| A6 | PF12 | A6 | | Address Bit 6 (RAM) |
| A7 | PF13 | A7 | | Address Bit 7 (RAM) |
| A8 | PF14 | A8 | | Address Bit 8 (RAM) |
| A9 | PF15 | A9 | | Address Bit 9 (RAM) |
| A2 | PF2  | A2 | | Address Bit 2 (RAM) |
| A3 | PF3  | A3 | | Address Bit 3 (RAM) |
| A4 | PF4  | A4 | | Address Bit 4 (RAM) |
| A5 | PF5  | A5 | | Address Bit 5 (RAM) |
| A10 | PG0  | A10 | | Address Bit 10 (RAM) |
| A11 | PG1  | A11 | | Address Bit 11 (RAM) |
| SDNCAS | PG15 | CAS | | Column Address Strobe (RAM) |
| BA0 | PG4  | BA0 | | Bank Address Bit 0 (RAM) |
| BA1 | PG5  | BA1 | | Bank Address Bit 1 (RAM) |
| SDCLK | PG8  | CLK | | Clock Signal for SDRAM (Microprocessor) |
| OSC_IN | PH1  | | | Oscillator Input (Microprocessor) |
| OSC_OUT | PH2  | | | Oscillator Output (Microprocessor) |
| Ve_guitare_L | | | LINEIN_L | Left Channel Input for Guitar Voltage |
| Ve_guitare_R | | | LINEIN_R | Right Channel Input for Guitar Voltage  |
| Vs_guitare_L | | | LINEOUT_L | Left Channel Output for Guitar Voltage  |
| Vs_guitare_R | | | LINEOUT_R | Right Channel Output for Guitar Voltage |

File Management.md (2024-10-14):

# Project Management

# State of the art

- First pedal creat in 1962 by Gibson.

  It was a Fuuz pedal.
  This invention came about thanks to the creation of transistors in 1947. This pedal was created to imitate the sound of a trumpet, saxophone or cello.
- In 80s, it's the arrival of the digital pedals.
  
   Digital electronics has revolutionised the world of electronic music, because before that there was only analogue electronics.
- In 90s arrival of multi-effect pedal.
 
  The use of pedals has been democratised with the advent of multi-effect pedals.
- In 2000s arrival of audio Plug In.
  
   All the effects are digital and controlled by computer.

# Functional Analysis
## Bulls diagram

<p align="center">
  Block Diagram
</p>
  
## Spider diagram
<p align="center">
  
</p>

## Specifications 

- **FP1** : Create a numerical pedal with several effects.
- **FC1** : Easy to use by the user.
- **FC2** : Power supply of 9V.
- **FC3** : Beautiful et practical.
- **FC4** : Environmentally friendly ( Respectful material, Low consuption).

# Organisation du groupe 
- Agile Method
- EXCEL : GANTT

To better organize our project, we have drawn up a task breakdown with each associated deliverable. This diagram is an integration of the WBS, OBS, and PBS charts.

WBS/OBS/PBS

- WBS = Work Breakdown Structure: hierarchical structures that break down complex operations into more manageable components
- PBS = Project Breakdown Structure: product organization chart: deliverables, breakdown, intermediate outputs
- OBS = Organization Breakdown Structure: How tasks are organized. The skills, responsibilities, relationships, etc. Individualization of tasks

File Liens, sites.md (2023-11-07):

# Link of website 🖱️

## Granular pedal of M.Fiack

https://www.hologramelectronics.com/microcosm

## fais tes effets de guitare 

https://fais-tes-effets-guitare.com

## Youtube du gars super fort : 
https://www.youtube.com/@PhilsLab

## Site pour trouver des montages : 
sonelec-music

## 🔊 Let's write a Reverb 

ADC21 conference about Musical Reverberation Effect (creation and implementation C++)

https://youtu.be/6ZK2Goiyotk?si=wrWfz4Z1EeCiMW1v

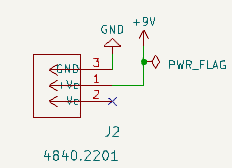
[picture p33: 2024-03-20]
Hardware/img/voltage input.png

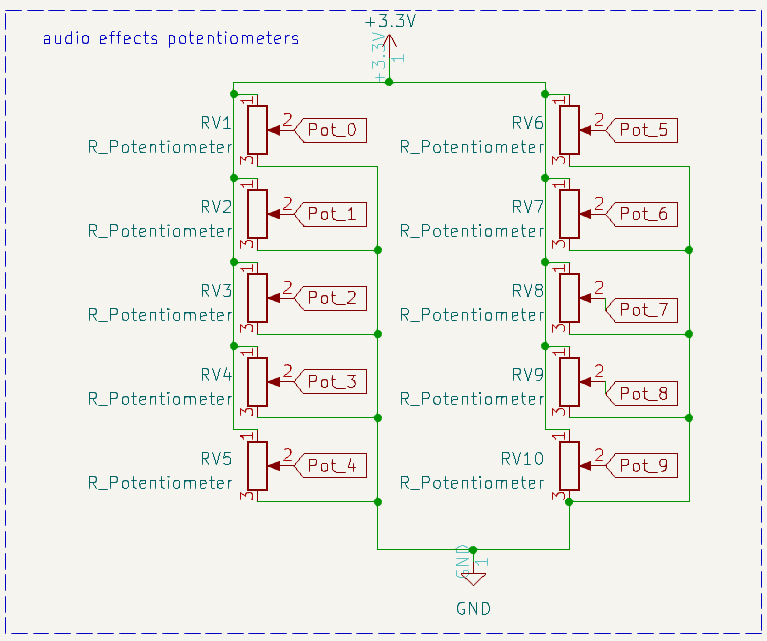
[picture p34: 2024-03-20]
Hardware/img/po.png

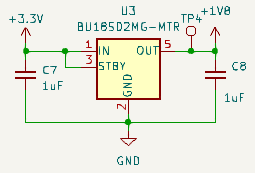
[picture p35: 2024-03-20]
Hardware/img/Linear_supply_1V8.png

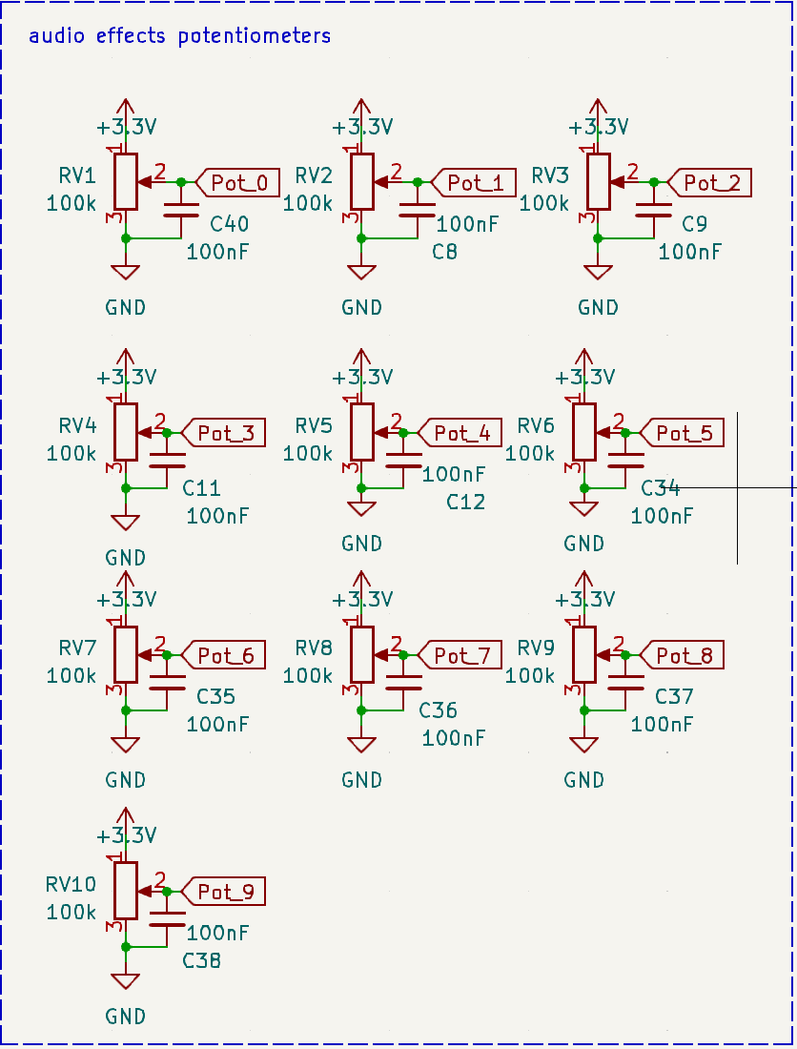
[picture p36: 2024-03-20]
Hardware/img/audio effects potentiometers.png

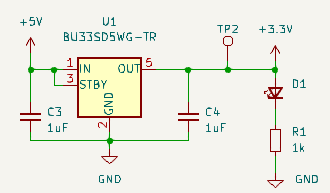
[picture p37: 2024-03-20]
Hardware/img/Linear_supply_3V.png

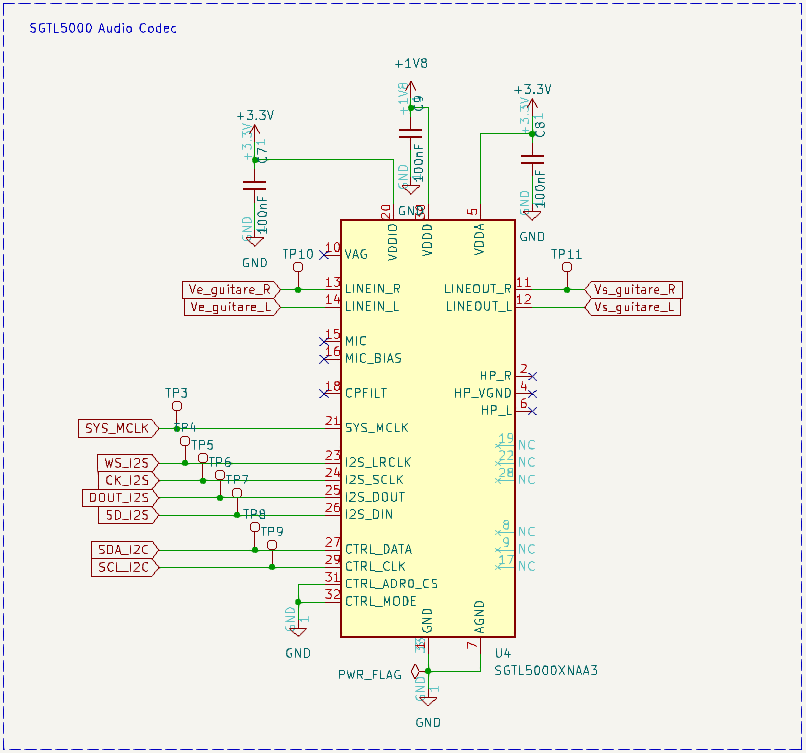
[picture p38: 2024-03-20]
Hardware/img/codec.png

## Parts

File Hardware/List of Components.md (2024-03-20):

# List of Components related to the block system
# A MODIF
[Return to Hardware Section](https://github.com/lucacros/2324_Projet2A_PedaleGuitare/tree/Hardware-Section)
## 📖 Table of contents

1. [Power section](#power-section)
2. [CODEC](#audio-codec)
3. [RAM](#ram)
4. [Microprocessor](#microprocessor)

# Power section

  - Resistor of 1k [E12 Series] 
  - Led [0.64x0.40mm]
  - 2 x Capacitor of 100µF.
  - 1 x Capacitor of 10µF.
  - 1 x Capacitor of 1µF
  - Regulator 173950578 :
  - Linear Regulator 5V/3.3V :
  - Linear Regulator 3.3V/1.8V :
  - DC plug 4840.2201 :

# Audio CODEC

   - 3 x Capacitor of 100µF.
   - **STGL5000**  :   [Link to data sheet](https://www.nxp.com/products/audio-and-radio/audio-converters/ultra-low-power-audio-codec:SGTL5000)

# R.A.M
   - 7 x Capacitor of 100µF
   - **IS42S16400J-xC** : [Link to data sheet](http://www.issi.com/WW/pdf/42-45S16400J.pdf)

# Microprocessor 

- 14 x Capacitor of 100µF : 13 for Etage d'alimentation
- 1 x Resistor of 510 Ohms
- **STM32F446ZCT6** : [Link to mouser website](https://www.mouser.fr/ProductDetail/STMicroelectronics/STM32F446ZCT6?qs=Ok1pvOkw6%2FqnUvQfUEqaFA%3D%3D)

# Switchs

- Buffer : Footswitch : [Link to mouser RS website](https://fr.rs-online.com/web/p/boutons-poussoirs/8466720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)
- Potar : Alpha RD901F
# Help
If a link is down go here to obtain all data sheets : [Link for all](https://github.com/lucacros/2324_Projet2A_PedaleGuitare/tree/Hardware-Section/data%20sheets)

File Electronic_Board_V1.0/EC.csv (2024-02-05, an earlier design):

Source: | C:\Users\Camille\Downloads\Electronic Board\EC.kicad_sch
Date: | 19/12/2023 11:16:07
Tool: | Eeschema (7.0.0)
Generator: | C:\Program Files\KiCad\7.0\bin\scripting\plugins/bom_csv_grouped_by_value.py
Component Count: | 96
Collated Components:
Item | Qty | Reference(s) | Value | LibPart | Footprint | Datasheet | DNP | LCSC Part
1 | 1 | C1 | 100uF | Device:C | Capacitor_SMD:C_0402_1005Metric_Pad0.74x0.62mm_HandSolder | ~
2 | 1 | C2 | 100µF | Device:C | Capacitor_SMD:C_0402_1005Metric_Pad0.74x0.62mm_HandSolder | ~
3 | 4 | C3, C4, C5, C6 | 1uF | Device:C_Small | Capacitor_SMD:C_0402_1005Metric_Pad0.74x0.62mm_HandSolder | ~ |  |  | C15849
4 | 34 | C7, C8, C9, C10, C11, C12, C13, C14, C15, C16, C20, C21, C22, C23, C24, C25, C26, C27, C28, C29, C30, C31, C32, C33, C40, C41, C42, C43, C44, C45, C46, C47, C48, C49 | 100nF | Device:C_Small | Capacitor_SMD:C_0402_1005Metric_Pad0.74x0.62mm_HandSolder | ~
5 | 1 | D2 | LED | Device:LED | LED_SMD:LED_0201_0603Metric_Pad0.64x0.40mm_HandSolder | ~
6 | 1 | D502 | RED | Device:LED_Small | LED_SMD:LED_0201_0603Metric_Pad0.64x0.40mm_HandSolder | ~
7 | 4 | H1, H2, H3, H4 | MountingHole_Pad | Mechanical:MountingHole_Pad | MountingHole:MountingHole_3.2mm_M3_DIN965_Pad | ~
8 | 4 | J1, J4, J5, J6 | NMJ4HCD2 | Connector_Audio:NMJ4HCD2 | Connector_Audio:Jack_6.35mm_Neutrik_NMJ4HCD2_Horizontal | https://www.neutrik.com/en/product/nmj4hcd2
9 | 1 | J2 | 4840.2201 | REGULATEUR 5V:4840.2201 | Library:Regulator4840-2201 | 4840.2201
10 | 1 | J3 | 173950578 | Regulator 5V:173950578 | Library:CONN3_950578_WRE_173950578 | 173950578
11 | 1 | R1 | 510 | Device:R | Resistor_SMD:R_0201_0603Metric_Pad0.64x0.40mm_HandSolder | ~
12 | 1 | R3 | 330 | Device:R | Resistor_SMD:R_0201_0603Metric_Pad0.64x0.40mm_HandSolder | ~
13 | 1 | R502 | 1k | Device:R_Small | Resistor_SMD:R_0603_1608Metric | ~
14 | 10 | RV1, RV2, RV3, RV4, RV5, RV6, RV7, RV8, RV9, RV10 | 100k | Device:R_Potentiometer | Library:Potentiometer_Alpha_RD901F-40-00D_Single_Vertical | ~
15 | 1 | SW2 | SW_SPDT | Switch:SW_SPDT | Library:RS_Pro_SPDT_8466720 | ~
16 | 25 | TP1, TP2, TP3, TP4, TP5, TP6, TP7, TP8, TP9, TP10, TP11, TP12, TP13, TP14, TP15, TP16, TP17, TP18, TP19, TP20, TP21, TP22, TP23, TP24, TP25 | TestPoint | Connector:TestPoint | TestPoint:TestPoint_Pad_D1.5mm | ~
17 | 1 | U2 | BU18SD2MG-MTR | WITNS_ROHM:BU18SD2MG-MTR | Package_TO_SOT_SMD:SOT-23-5 | https://fscdn.rohm.com/en/products/databook/datasheet/ic/power/linear_regulator/buxxsd2mg-m-e.pdf |  |  | C3750384
18 | 1 | U4 | SGTL5000XNAA3 | Audio:SGTL5000XNAA3 | Package_DFN_QFN:QFN-32-1EP_5x5mm_P0.5mm_EP3.6x3.6mm | https://www.nxp.com/docs/en/data-sheet/SGTL5000.pdf
19 | 1 | U5 | IS42S16400J-xC | Memory_RAM:IS42S16400J-xC | Package_SO:TSOP-II-54_22.2x10.16mm_P0.8mm | http://www.issi.com/WW/pdf/42-45S16400J.pdf
20 | 1 | U6 | STM32F446ZCTx | MCU_ST_STM32F4:STM32F446ZCTx | Package_QFP:LQFP-144_20x20mm_P0.5mm | https://www.st.com/resource/en/datasheet/stm32f446zc.pdf
21 | 1 | U502 | BU33SD5WG-TR | WITNS_ROHM:BU33SD5WG-TR | Package_TO_SOT_SMD:SOT-23-5 | https://fscdn.rohm.com/en/products/databook/datasheet/ic/power/linear_regulator/buxxsd5wg-e.pdf

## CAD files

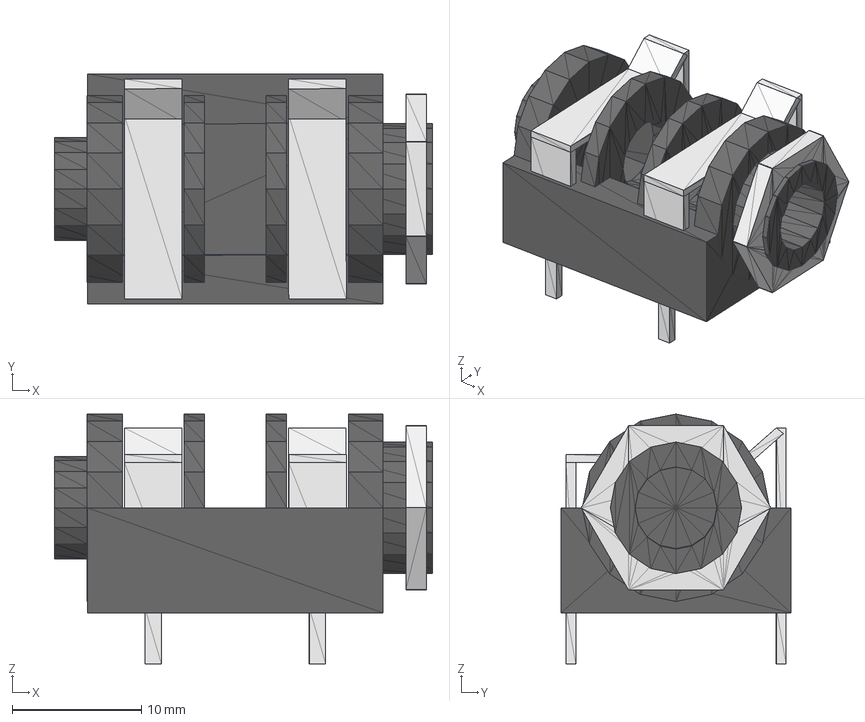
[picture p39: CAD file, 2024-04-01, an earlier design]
Electronic_Board_V1.0/NEUTRIKJK.stp
29.2 x 17.8 x 19.3 mm
NEUTRIKJK_2
NEUTRIKJK_3
NEUTRIKJK_4
NEUTRIKJK_5
NEUTRIKJK_6
NEUTRIKJK_7
NEUTRIKJK_8
NEUTRIKJK_9
NEUTRIKJK_10
NEUTRIKJK_11
NEUTRIKJK_12
NEUTRIKJK_13
NEUTRIKJK_14
NEUTRIKJK_15
NEUTRIKJK_16
NEUTRIKJK_17
NEUTRIKJK_18
NEUTRIKJK_19
NEUTRIKJK_20
NEUTRIKJK_21
NEUTRIKJK_22
NEUTRIKJK_23
NEUTRIKJK_24
NEUTRIKJK_25
NEUTRIKJK_26

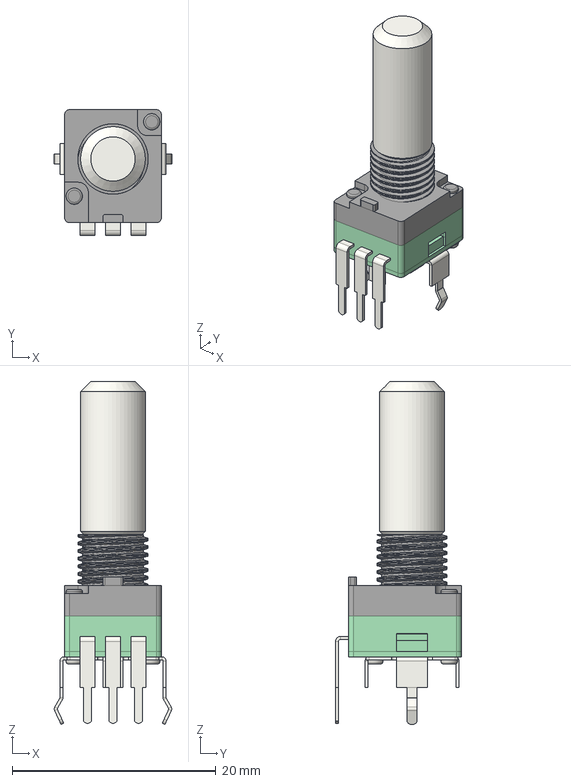
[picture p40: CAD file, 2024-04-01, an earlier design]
Electronic_Board_V1.0/ALPHA-RD901F-40.step
11.5 x 12.4 x 33.6 mm

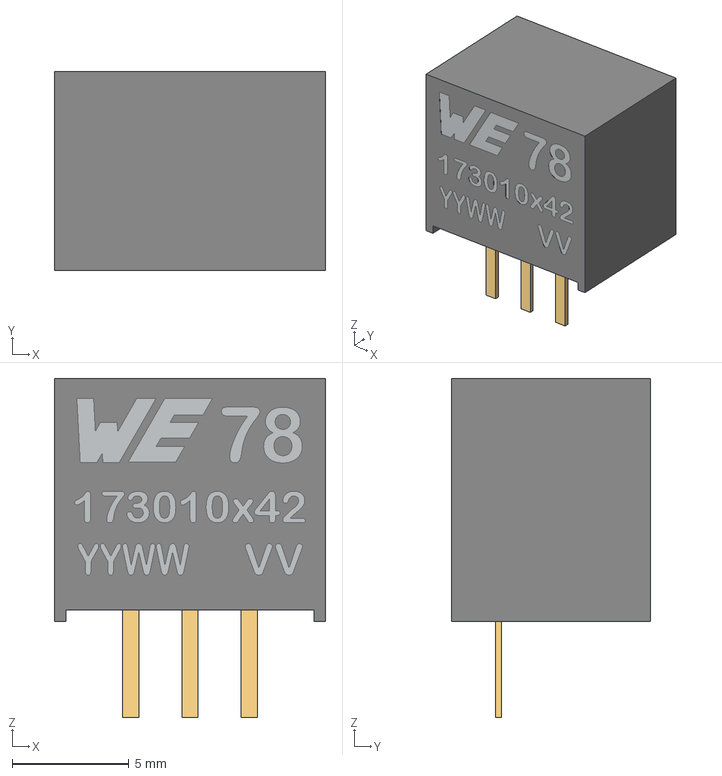
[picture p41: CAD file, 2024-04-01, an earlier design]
Electronic_Board_V1.0/173010342_STP_173010342_rev1.stp
11.6 x 8.50 x 14.5 mm

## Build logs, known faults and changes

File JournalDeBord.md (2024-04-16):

# Journal de bord 📰

## Table of contents

- [Session 1](#session-1)
- [Session 2](#session-2)
- [Session 3](#session-3)
- [Session 4](#session-4)
- [Session 5](#session-5)
- [Session 6](#session-6)
- [Session 7](#session-7)
- [Session 8](#session-8)
- [Session 9](#session-9)
- [Session 10](#session-10)
- [Session 11](#session-11)
- [Session 12](#session-12)
- [Session 13](#session-13)
- [Session 14](#session-14)
- [Session 15](#session-15)
- [Session 16](#session-16)
- [Session 17](#session-17)
- [Session 18](#session-18)
- [Session 19](#session-19)
- [Session 20](#session-20)
- [Session 21](#session-21)
- [Session 22](#session-22)

## Session 1
### 19/09

Presentation of 2nd year projects, explanation of grading criteria and expectations.

Allocated budget of €40 per head. Spreadsheet for orders (available soon).

Brainstorming started

I've managed to join the github. (Jolan)

Study of the Supercell module on the RACKV2 software, presented by our mentor Mr. Fiack.

Buffer with 40 read heads (instead of one). With different positions. Each head has a wrapper. The trigg has a density. Pitch at 0 (= delay), pitch at high density (small clicks). Shape changes the shape of the envelope. Density, number of playback heads played.

## Session 2
### 26/09

### Definition of codec (wiki) : 

A codec is a hardware or software device used to encode or decode a digital data stream for transmission or storage. Some codecs also incorporate a data compression or encryption function.
The acronym "codec" comes from "coder-decoder".

Manufacturing steps : 

- Select components (codec + microprocessor)

- Design the PCB in Kikad

- Code the effect in CubeIDE

## Session 3
### 03/10 

We measured the signal sent by a guitar to be able to correctly size a preamp that will send the guitar signal to the codec.
We have to look at existing guitar effect models to find out how to make a programme to code them in C and implement them in the microprocessor.

## Session 4
### 10/10

We gave our first presentation on the progress of our project. 
Several things needed to be reviewed, including the part with the regulators to feed each part of the board correctly. 
M.Papazouglou told us to use Faust, which is a block programming language. This language is designed for signal processing.
https://github.com/lucacros/2324_Projet2A_PedaleGuitare/blob/main/2324_Projet2A_PedaleGuitare_Présentation_10-10-23.pptx

## Session 5
### 17/10

Design of the pedal's preamplifier on a simulation software. We opted for a non-inverting circuit. 
Start of the design of the codec, RAM and microprocessor on Kicad.
Approaching the Faust programming language.

## Session 6
### 24/10

Continuation of the PCB Design. Check that all pins are connected correctly on the microprocessor.
Creating a digital effect in Faust like reverb or distortion and converting it to a .c file

## Session 7
### 07/11

2nd presentation of our progress. (https://github.com/lucacros/2324_Projet2A_PedaleGuitare/blob/main/2324_Projet2A_PedaleGuitare_Présentation_07-11-23.pdf)
We have to make a lot of changes especially for the component (AOP LM324 has to be replaced by a better one with less distortion).
For the AOP we choose the MCP6002.

Correction of wiring diagram errors : 
- modification of the power supply circuit
-> addition of a switching regulator

- addition of switching regulators
- modification of µP/SGTL5000 wiring:

## Session 8
### 14/11
Design of the Buffer boton and research for the component. 
Modification of the KiCad schematic according to our teachers intrutions.
Research and documentation on the operation of the Codec, ADC,DAC and DMA so that we can integrate it as effectively as possible into our pedal.

## Session 9
### 28/11

Correction of the errors of the schematic on KiCad to prepare the rooting.
Manipulation of the ADC and DAC to recover our audio input and output on stm32cubeIDE. The purpose of this is to prepare for handling the CODEC.

## Session 10
### 05/12

We made our 3rd presentation to show the progress of our project. 
Some parts need to be revised, such as the reference for a regulator, adding mute jacks (2 at the input and 2 at the output) to be able to warn stereo at the input and output, and adding a VDDD voltage of 1.8V. 
https://github.com/lucacros/2324_Projet2A_PedaleGuitare/blob/main/2324_Projet2A_PedaleGuitare_Présentation_05-12-23.pdf

## Session 11
### 12/12

Creation of a simple distortion effect to validate codec manipulation

**Distorsion Effect**



We've added switched jacks on the input and output sides of the pedal, so we can use 2 mono jacks on the input side and 2 mono jacks on the output side. 
We design some component that are not in the library of KiCad like the footswitch of the buffer.
The last errors on the schematic have been resolved and the PCB routing can now begin.

## Session 12
### 19/12

Continued rooting of the PCB.
We update update the Github to have all our work up to date on the Github.

## Session 13
### 16/01

Meeting to review achievements and objectives for the 2nd semester.
-  Redesign and adjustment of the PCB.
-  Start of the design of the box that will house the PCB.

## Session 14
### 23/01

Improving the design of the box: The drawer system used to close the box wasn't adapted enough. 
So we decided to make the box in two parts that screw together to close the box.

## Session 15
### 30/01

Modelling of the new locking system. 
This system consists of a cover that is fixed to the underside of the pedal using screws.

## Session 16
### 6/02
After a first impression we realised that there were a number of design problems, including the fact that the 2 parts didn't fit together properly. 
So we made a number of adjustments, such as adjusting the position of the holes for the jacks, a hole for the power supply, adjusting the height of the screw supports so that they were perfectly level with the lid and enlarging the surface area of the footswitch to avoid having to press several buttons at the same time with your foot when you wanted to activate the footswitch.

## Session 17
### 27/02

A number of adjustments have been made to the 3D model of the pedal, including enlarging the holes to ensure that the potentiometers and jacks fit properly into the case.

Starting to create a delay effect on Faust. 

## Session 18
### 05/03

We gave a presentation on our progress. 
The box was incorrectly calibrated due to a dimensioning error, which was quickly resolved.

## Session 19
### 12/03
We looked at the different effects we could create to get the maximum effect before the end of the project.
We started the creation of a chorus effect, a reverb effect and an overdrive effect.

## Session 20
### 19/03

We continued to develop the digital effects on the pedal, but encountered several problems. The first was the Faust encoded reverb effect. This effect took up too much space on the microprocessor, which prevented us from testing it and checking that it was working properly. 
We also couldn't create a chorus effect correctly because of problems with buffer management in the C code. In fact, when we tested the effect on a computer, there were cuts in the output audio.

## Session 21
### 26/03

Placement of all 3D prints on the PCB.
Testing the distortion effects.
We couldn't find a solution for the Chorus effect to work properly.

## Session 22
### 02/04

Final presentation of our project and demonstration of the various distortion effects on an electric guitar.

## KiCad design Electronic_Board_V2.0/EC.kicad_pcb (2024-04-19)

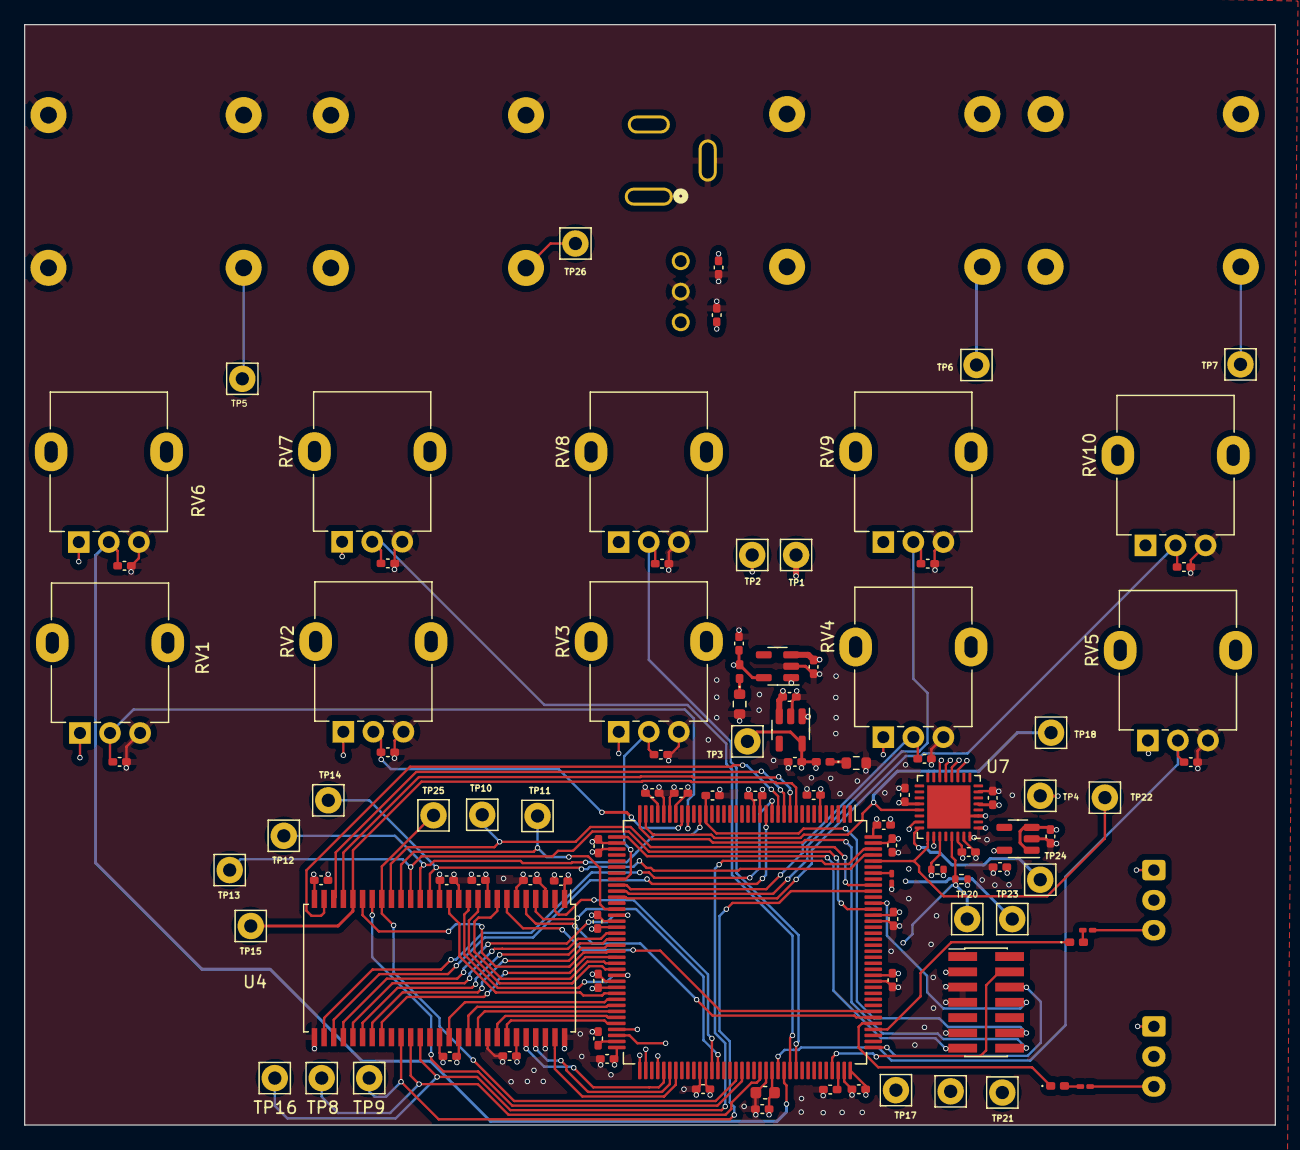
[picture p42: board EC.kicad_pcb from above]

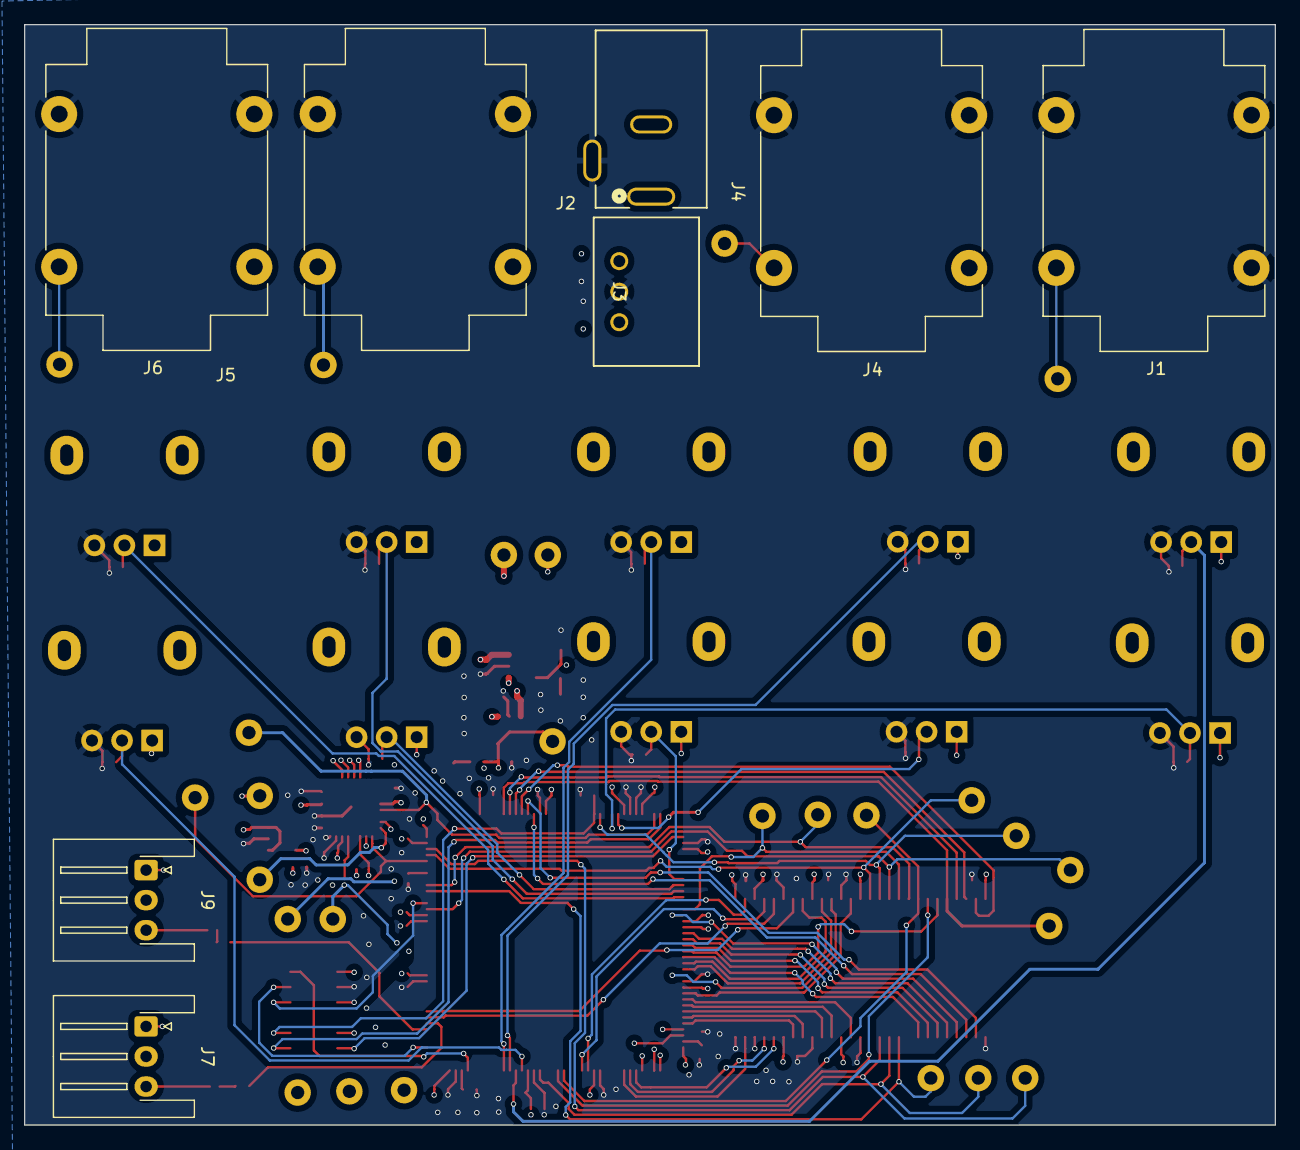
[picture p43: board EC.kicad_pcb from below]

Board: 6 copper layers, 104.0 x 91.5 mm, 109 parts (8 on the bottom side), 82 nets.

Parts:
C1: 100uF; C_0402_1005Metric_Pad0.74x0.62mm_HandSolder
C2: 100µF; C_0402_1005Metric_Pad0.74x0.62mm_HandSolder
C3, C4, C5, C6, C7, C8: 1uF; C_0402_1005Metric_Pad0.74x0.62mm_HandSolder
C9, C10, C11, C12, C13, C14, C15, C20, C21, C22, C23, C24, C25, C26, C27, C28, C29, C30, C31, C32, C33, C34, C35, C40, C41, C42, C43, C44, C45, C46, C47, C48, C49, C50, C51, C60: 100nF; C_0402_1005Metric_Pad0.74x0.62mm_HandSolder
C17: 4.7u; C_0603_1608Metric
C18, C19: 2.2uF; C_0402_1005Metric_Pad0.74x0.62mm_HandSolder
D1, D3: RED; LED_0402_1005Metric_Pad0.77x0.64mm_HandSolder
D2, D4: LED; LED_0402_1005Metric_Pad0.77x0.64mm_HandSolder
J1, J4, J5, J6: NMJ4HCD2; Jack_6.35mm_Neutrik_NMJ4HCD2_Horizontal
J2: 4840.2201 power connector; Regulator4840-2201
J3: 173950578; CONN3_950578_WRE_173950578
J7, J9: Conn_01x03; JST_XH_S3B-XH-A-1_1x03_P2.50mm_Horizontal
J8: Conn_02x07_Odd_Even; PinHeader_2x07_P1.27mm_Vertical_SMD
R1, R2: 1k; R_0603_1608Metric
R3, R4: 330; R_0201_0603Metric_Pad0.64x0.40mm_HandSolder
R5, R7: 1.5k; R_0402_1005Metric
R6: 510; R_0201_0603Metric_Pad0.64x0.40mm_HandSolder
RV1, RV2, RV3, RV4, RV5, RV6, RV7, RV8, RV9, RV10: 100k; Potentiometer_Alpha_RD901F-40-00D_Single_Vertical
TP1, TP2, TP3, TP4, TP5, TP6, TP7, TP8, TP9, TP10, TP11, TP12, TP13, TP14, TP15, TP16, TP17, TP18, TP19, TP20, TP21, TP22, TP23, TP24, TP25, TP26: TestPoint; Pin_D1.1mm_L8.5mm_W2.5mm_FlatFork
U1, U2: BU33SD5WG-TR; SOT-23-5
U3: BU18SD2MG-MTR; SOT-23-5
U4: IS42S16400J-xC; TSOP-II-54_22.2x10.16mm_P0.8mm
U6: STM32F446ZCTx; LQFP-144_20x20mm_P0.5mm
U7: SGTL5000XNAA3; QFN-32-1EP_5x5mm_P0.5mm_EP3.6x3.6mm

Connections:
+1V8: C8.1, C51.1, TP4.1, U3.5 (OUT), U7.30 (VDDD)
+3.3V: C4.1, C7.1, C9.1, C10.1, C11.1, C12.1, C13.1, C14.1, C15.1, C17.1, C20.1, C21.1, C22.1, C23.1, C25.1, C26.1, C27.1, C28.1, C29.1, C30.1, C31.1, C32.1, C33.1, C34.1, C35.1, D1.2 (A), J7.1, J8.3, J9.1, R5.1, R7.1, RV1.1, RV2.1, RV3.1, RV4.1, RV5.1, RV6.1, RV7.1, RV8.1, RV9.1, RV10.1, TP2.1, U1.5 (OUT), U3.1 (IN), U3.3 (STBY), U4.1 (VDD), U4.3 (VDDQ), U4.9 (VDDQ), U4.14 (VDD), U4.27 (VDD), U4.43 (VDDQ), U4.49 (VDDQ), U6.6 (VBAT), U6.17 (VDD), U6.30 (VDD), U6.39 (VDD), U6.52 (VDD), U6.62 (VDD), U6.72 (VDD), U6.84 (VDD), U6.95 (VDDUSB), U6.108 (VDD), U6.121 (VDD), U6.131 (VDD), U6.143 (PDR_ON), U6.144 (VDD), U7.20 (VDDIO)
+3.3VA: C6.1, C24.1, C50.1, D3.2 (A), TP3.1, U2.5 (OUT), U6.33 (VDDA), U7.5 (VDDA)
+5V: C2.1, C3.1, C5.1, J3.3 (Vs), TP1.1, U1.1 (IN), U1.3 (STBY), U2.1 (IN), U2.3 (STBY)
+12V: C1.1, J2.1 (+Ve), J3.1 (+Ve)
/Codec/CK_I2S: TP24.1, U6.74 (PB13), U7.24 (I2S_SCLK)
/Codec/DOUT_I2S: TP22.1, U6.140 (PB9), U7.25 (I2S_DOUT)
/Codec/SCL_I2C: R7.2, TP20.1, U6.69 (PB10), U7.29 (CTRL_CLK)
/Codec/SDA_I2C: R5.2, TP19.1, U6.70 (PB11), U7.27 (CTRL_DATA)
/Codec/SD_I2S: TP21.1, U6.76 (PB15), U7.26 (I2S_DIN)
/Codec/SYS_MCLK: TP18.1, U6.35 (PA1), U7.21 (SYS_MCLK)
/Codec/Ve_guitare_L: J1.T, J4.TN, TP5.1, U7.14 (LINEIN_L)
/Codec/Ve_guitare_R: J4.T, TP26.1, U7.13 (LINEIN_R)
/Codec/Vs_guitare_L: J5.T, TP6.1, U7.12 (LINEOUT_L)
/Codec/Vs_guitare_R: J6.T, TP7.1, U7.11 (LINEOUT_R)
/Codec/WS_I2S: TP23.1, U6.73 (PB12), U7.23 (I2S_LRCLK)
/STM32/A0: TP15.1, U4.23 (A0), U6.10 (PF0)
/STM32/A1: U4.24 (A1), U6.11 (PF1)
/STM32/A2: U4.25 (A2), U6.12 (PF2)
/STM32/A3: U4.26 (A3), U6.13 (PF3)
/STM32/A4: U4.29 (A4), U6.14 (PF4)
/STM32/A5: U4.30 (A5), U6.15 (PF5)
/STM32/A6: U4.31 (A6), U6.50 (PF12)
/STM32/A7: U4.32 (A7), U6.53 (PF13)
/STM32/A8: U4.33 (A8), U6.54 (PF14)
/STM32/A9: U4.34 (A9), U6.55 (PF15)
/STM32/A10: U4.22 (A10), U6.56 (PG0)
/STM32/A11: U4.35 (A11), U6.57 (PG1)
/STM32/BA0: TP25.1, U4.20 (BA0), U6.89 (PG4)
/STM32/BA1: U4.21 (BA1), U6.90 (PG5)
/STM32/D0: TP17.1, U4.2 (DQ0), U6.85 (PD14)
/STM32/D1: U4.4 (DQ1), U6.86 (PD15)
/STM32/D2: U4.5 (DQ2), U6.114 (PD0)
/STM32/D3: U4.7 (DQ3), U6.115 (PD1)
/STM32/D4: U4.8 (DQ4), U6.58 (PE7)
/STM32/D5: U4.10 (DQ5), U6.59 (PE8)
/STM32/D6: U4.11 (DQ6), U6.60 (PE9)
/STM32/D7: U4.13 (DQ7), U6.63 (PE10)
/STM32/D8: U4.42 (DQ8), U6.64 (PE11)
/STM32/D9: U4.44 (DQ9), U6.65 (PE12)
/STM32/D10: U4.45 (DQ10), U6.66 (PE13)
/STM32/D11: U4.47 (DQ11), U6.67 (PE14)
/STM32/D12: U4.48 (DQ12), U6.68 (PE15)
/STM32/D13: U4.50 (DQ13), U6.77 (PD8)
/STM32/D14: U4.51 (DQ14), U6.78 (PD9)
/STM32/D15: U4.53 (DQ15), U6.79 (PD10)
/STM32/NBL0: TP14.1, U4.15 (LDQM), U6.141 (PE0)
/STM32/NBL1: TP16.1, U4.39 (UDQM), U6.142 (PE1)
/STM32/SDCKE1: TP9.1, U4.37 (CKE), U6.135 (PB5)
/STM32/SDCLK: TP8.1, U4.38 (CLK), U6.93 (PG8)
/STM32/SDNCAS: TP13.1, U4.17 (~CAS), U6.132 (PG15)
/STM32/SDNE1: TP10.1, U4.19 (~CS), U6.136 (PB6)
/STM32/SDNRAS: TP11.1, U4.18 (~RAS), U6.49 (PF11)
/STM32/SDNWE: TP12.1, U4.16 (~WE), U6.26 (PC0)
GND: C1.2, C2.2, C3.2, C4.2, C5.2, C6.2, C7.2, C8.2, C9.2, C10.2, C11.2, C12.2, C13.2, C14.2, C15.2, C17.2, C18.2, C19.2, C20.2, C21.2, C22.2, C23.2, C24.2, C25.2, C26.2, C27.2, C28.2, C29.2, C30.2, C31.2, C32.2, C33.2, C34.2, C35.2, C40.2, C41.2, C42.2, C43.2, C44.2, C45.2, C46.2, C47.2, C48.2, C49.2, C50.2, C51.2, C60.2, J1.S, J1.SN, J1.TN, J2.3 (GND), J3.2 (GND), J4.S, J4.SN, J5.S, J5.SN, J6.S, J6.SN, J8.5, J8.7, J8.11, R1.2, R2.2, R6.1, RV1.3, RV2.3, RV3.3, RV4.3, RV5.3, RV6.3, RV7.3, RV8.3, RV9.3, RV10.3, U1.2 (GND), U2.2 (GND), U3.2 (GND), U4.6 (GNDQ), U4.12 (GNDQ), U4.28 (GND), U4.41 (GND), U4.46 (GNDQ), U4.52 (GNDQ), U4.54 (GND), U6.16 (VSS), U6.31 (VSSA), U6.32 (VREF+), U6.38 (VSS), U6.51 (VSS), U6.61 (VSS), U6.83 (VSS), U6.94 (VSS), U6.107 (VSS), U6.120 (VSS), U6.130 (VSS), U7.1 (GND), U7.3 (GND), U7.7 (AGND), U7.31 (CTRL_ADR0_CS), U7.32 (CTRL_MODE), U7.33 (GND)
NRST: C60.1, J8.12, U6.25 (NRST)
unnamed: D1.1 (K), R1.1
unnamed: D2.2 (A), R3.1
unnamed: D2.1 (K), U6.112 (PC11)
unnamed: D3.1 (K), R2.1
unnamed: D4.2 (A), R4.1
unnamed: D4.1 (K), U6.113 (PC12)
unnamed: J7.3, R4.2
unnamed: J9.3, R3.2
unnamed: R6.2, U6.138 (BOOT0)
unnamed: C18.1, U6.71 (VCAP_1)
unnamed: C19.1, U6.106 (VCAP_2)
Pot_0: C40.1, RV1.2, U6.28 (PC2)
Pot_1: C41.1, RV2.2, U6.29 (PC3)
Pot_2: C42.1, RV3.2, U6.44 (PC4)
Pot_3: C43.1, RV4.2, U6.45 (PC5)
Pot_4: C44.1, RV5.2, U6.96 (PC6)
Pot_5: C45.1, RV6.2, U6.97 (PC7)
Pot_6: C46.1, RV7.2, U6.98 (PC8)
Pot_7: C47.1, RV8.2, U6.99 (PC9)
Pot_8: C48.1, RV9.2, U6.46 (PB0)
Pot_9: C49.1, RV10.2, U6.47 (PB1)
SWCLK: J8.6, U6.109 (PA14)
SWDIO: J8.4, U6.105 (PA13)
SWO: J8.8, U6.133 (PB3)
USART2_RX: J8.13, U6.37 (PA3)
USART2_TX: J8.14, U6.36 (PA2)
